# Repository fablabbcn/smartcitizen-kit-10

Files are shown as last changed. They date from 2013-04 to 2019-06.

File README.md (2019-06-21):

Smart Citizen Kit
=================

**NOTE:** [Click here](https://github.com/fablabbcn/smartcitizen-kit-20) for the newer version of SCK 2.0+

**Smart Citizen Kit BETA version for the Ambient Sensor Board.**

SCK

### Download

* Download the latest firmware release [here](https://github.com/fablabbcn/Smart-Citizen-Kit/releases/latest).

### Hardware

* Firmware for the [SmartCitizen Ambient Kit](http://smartcitizen.me/pages/sck) 1.0 and 1.1.

* More hardware info [here](https://github.com/fablabbcn/Smart-Citizen-Kit/tree/master/hardware).

### Quick start

* Visit the project main documentation [docs.smartcitizen.me](http://docs.smartcitizen.me)

### Loading Firmware

**The firmware is totally compatible with Arduino. You can upload the firmware using the [Arduino IDE](http://arduino.cc/en/main/software).**

* For SmartCitizen Kit version 1.0 select `Tools/Boards/Arduino Leonardo` on the Arduino IDE (ATmega 32U4 at 16Mhz) 

* For SmartCitizen Kit version 1.1 select `Tools/Boards/Lylipad Arduino USB` on the Arduino IDE (ATmega 32U4 at 8Mhz) 

### Versions

The current firmware version in use is `0.9.4`.

We currently support the SD card version on as a diferent firmware `SDCARD`, currently `0.8.7 SDCARD`.

You can see the release history [here](https://github.com/fablabbcn/Smart-Citizen-Kit/releases)

You can see the hardware versions [here](https://github.com/fablabbcn/Smart-Citizen-Kit/blob/master/hardware/README.md)

### Advance References

* Setup commands reference in [sck-commands.md](https://github.com/fablabbcn/Smart-Citizen-Kit/blob/master/sck-commands.md)

* Basic documentation for creating your own Sensor Boards [here](https://github.com/fablabbcn/Smart-Citizen-Kit/wiki/Making-a-Shield)

* [Slideshow](https://speakerdeck.com/pral2a/smart-citizen-hardware-and-software) with project technical details

### Support and issues

* Forum [forum.smartcitizen.me](http://forum.smartcitizen.me)

### Contributions

* We are working on improving the firmware documentation for developers but still we encourage you to Fork the project and do a Pull request with your contributions.

## License

All the software unless stated is released under [GNU GPL v3.0](https://github.com/fablabbcn/smartcitizen-kit/blob/master/LICENSE) and the hardware design files under [CERN OHL v1.2](https://github.com/fablabbcn/smartcitizen-kit/blob/master/hardware/LICENSE)

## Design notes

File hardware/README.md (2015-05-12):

Smart Citizen Kit
=================

###Smart Citizen Kit Ambient Sensor Board versions

| Smart Citizen Kit | | SCK 1.0 (Goteo Board) | SCK 1.1 (Kickstarter Board) |
|:---|:---:|:---:|:---:|
| **Data Board** | | | |
| **MCU** | | ATMEGA32U4 | ATMEGA32U4 |
| **Clock** | | 16Mhz | 8Mhz |
| **WiFi** | | Microchip RN-131 802.11 b/g | Microchip RN-131 802.11 b/g |
| **Firmware** | | https://github.com/fablabbcn/Smart-Citizen-Kit | https://github.com/fablabbcn/Smart-Citizen-Kit |
| **Design files** | | https://github.com/fablabbcn/Smart-Citizen-Kit/tree/master/hardware/Goteo/v1.01  | https://github.com/fablabbcn/Smart-Citizen-Kit/tree/master/hardware/Kickstarter |
| **Ambient Board** | | | |
| **Light** | *Part* | PVD-P8001 | BH1730FVC |
| | *Type* | LDR Analog Light Sensor | Digital Ambient Light Sensor |
| | *Units* | % | Lux |
| | *Datasheet* | https://github.com/fablabbcn/Smart-Citizen-Kit/wiki/Datasheets/PDV-P8001.pdf | https://github.com/fablabbcn/Smart-Citizen-Kit/wiki/Datasheets/BH-1730FCV.pdf |
| | Firmware  | `SCKAmbient::getLight();` | `SCKAmbient::getLight():` |
| **Temp** | *Part* | DHT22 | HPP828E031 (SHT21) |
| | *Type* | Digital Temperature and Relative Humidity Sensor | Digital Temperature and Relative Humidity Sensor |
| | *Units* | ºC | ºC |
| | *Datasheet* | https://github.com/fablabbcn/Smart-Citizen-Kit/wiki/Datasheets/DHT22.pdf | https://github.com/fablabbcn/Smart-Citizen-Kit/wiki/Datasheets/HTU-21D.pdf |
| | Firmware  | `SCKAmbient::getDHT22();` `SCKAmbient::getHumidity();` | `SCKAmbient::getSHT21();` `SCKAmbient::getTemperature();` |
| **Humidity** | *Part* | DHT22 | HPP828E031 (SHT21) |
| | *Type* | Digital Temperature and Relative Humidity Sensor | Digital Temperature and Relative Humidity Sensor |
| | *Units* | % Rel | % Rel |
| | *Datasheet* | https://github.com/fablabbcn/Smart-Citizen-Kit/wiki/Datasheets/DHT22.pdf | https://github.com/fablabbcn/Smart-Citizen-Kit/wiki/Datasheets/HTU-21D.pdf |
| | Firmware  | `SCKAmbient::getDHT22();` `SCKAmbient::getHumidity();` | `SCKAmbient::getSHT21();` `SCKAmbient::getHumidity();` |
| **Noise** | *Part* | POM-3044P-R | POM-3044P-R |
| | *Type* | Electret microphone with envelop follower sound pressure sensor | Electret microphone with envelop follower sound pressure sensor |
| | *Units* | dB | dB |
| | *Datasheet* | https://github.com/fablabbcn/Smart-Citizen-Kit/wiki/Datasheets/POM-3044P-R.pdf | https://github.com/fablabbcn/Smart-Citizen-Kit/wiki/Datasheets/POM-3044P-R.pdf |
| | *Firmware*  | `SCKAmbient::getNoise();` | `SCKAmbient::getNoise();` |
| **CO** | *Part* | MICS-5525 | MiCS-4514 |
| | *Type* | MOS CO gas sensor | MOS CO and NO2 gas sensor |
| | *Units* | kOhm (ppm) | kOhm (ppm) |
| | *Datasheet* | https://github.com/fablabbcn/Smart-Citizen-Kit/wiki/Datasheets/MICS-5525_CO.pdf  | https://github.com/fablabbcn/Smart-Citizen-Kit/wiki/Datasheets/MiCS-4514_CO_NO2.pdf |
| | *Firmware*  | `SCKAmbient::getMICS();` | `SCKAmbient::getMICS();` |
| **NO2** | *Part* | MICS-2710 | MiCS-4514 |
| | *Type* | MOS NO2 gas sensor | MOS CO and NO2 gas sensor |
| | *Units* | kOhm (ppm) | kOhm (ppm) |
| | *Datasheet* | https://github.com/fablabbcn/Smart-Citizen-Kit/wiki/Datasheets/MICS-2710_NO2.pdf | https://github.com/fablabbcn/Smart-Citizen-Kit/wiki/Datasheets/MiCS-4514_CO_NO2.pdf |
| | *Firmware*  | `SCKAmbient::getMICS();` | `SCKAmbient::getMICS();` |

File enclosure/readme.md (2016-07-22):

Smartcitizen Kit Enclosure
====

## Enclosure (info [video](https://vimeo.com/145620646))
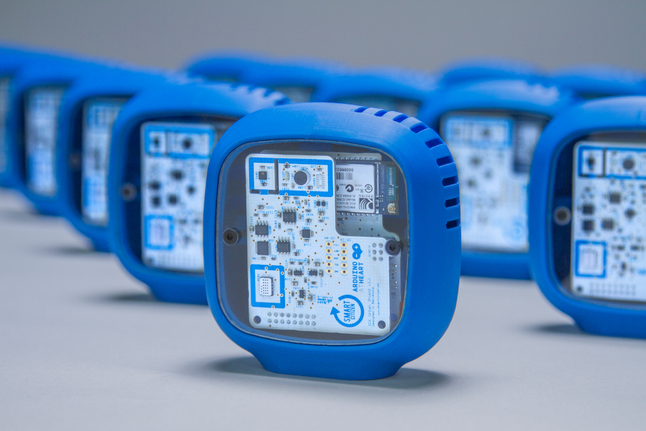
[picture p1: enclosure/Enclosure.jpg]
Enclosure


## Simple base
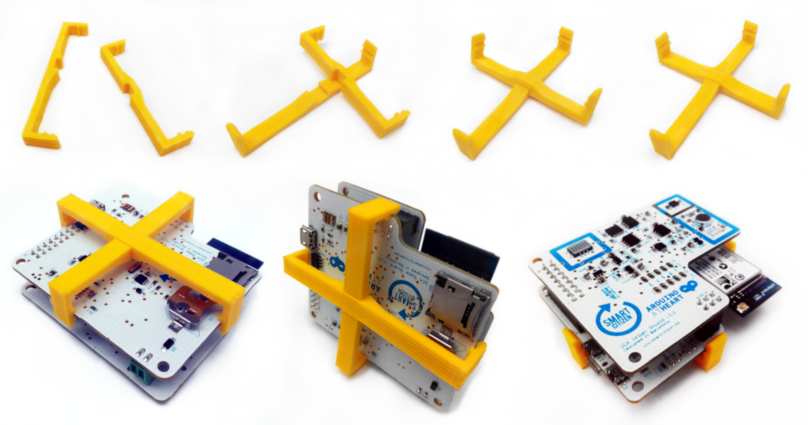
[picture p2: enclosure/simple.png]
Simple base


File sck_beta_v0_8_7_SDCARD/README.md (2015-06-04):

Smart Citizen Kit firmware for SD
=================================

**Smart Citizen Kit SD firmware version for the Ambient Sensor Board.**

This firmware is aimed to people wanting to log data in off-line mode, without internet connectivity, storing data on the built-in micro SD.

##Steps

1. **microSD**: We recomend formating **micro SD** cards using the official SD tool you can download [here](https://www.sdcard.org/downloads/formatter_4/).

2. **RTC**: Place a **CR1220** cell battery on your kit. Before uploading the SD firmware use the on-line configuration tool at [smartcitizen.me](https://smartcitizen.me) to set your Wi-Fi credentials. Your kit will connect to the internet and sync its the internal clock with our remote servers.

3. You can now install the **SD firmware** using the Arduino IDE. Ready!

##Installation

**The firmware is totally compatible with Arduino. You can upload the firmware using the [Arduino IDE](http://arduino.cc/en/main/software).**

####Dependencies: 

In order to compile and upload the firmware you will need to install the **SdFat** library for Arduino.

Download the library [here](https://github.com/greiman/SdFat) and install the library following the [instructions](http://arduino.cc/en/Guide/Libraries).

####Boards:

* For SmartCitizen Kit version 1.0 select `Tools/Boards/Arduino Leonardo` on the Arduino IDE (ATmega 32U4 at 16Mhz) 

* For SmartCitizen Kit version 1.1 select `Tools/Boards/Lylipad Arduino USB` on the Arduino IDE (ATmega 32U4 at 8Mhz) 

##SD data format

When using the **SD firmware** on the SCK, data is stored as **CSV** (comma separated) file on the SD card.

This is an example of the output file once opened on a spreadsheet application:

| Temperature | Humidity| Light | Battery | Solar Panel | CO | NO2  | Noise| UTC			  	 | 
|---|---|---|---|---|---|---|---|---|
| 2821.20 | 4072.00 | 4413.10 | 96.40 | 0.00 | 94.67  | 0.65 | 5.23 | 2000-01-01  00:00:02 |
| 2784.40 | 4236.80 | 5936.70 | 96.10 | 0.00 | 278.27 | 1.05 | 2.39 | 2000-01-01  00:00:02 |

###Data Import

You can import the recorded data in to [smartcitizen.me](http://smartcitizen.me).

In your device page you will find the **Import SD** along with the Edit and Configure options.



Using a microSD card reader get the **post.csv** file from your card, select it and click import. Data will be imported in to your device, data existing on the file already imported will be skipped. Your kit should be running the latest SD firmware  and the SCK time (RTC) should be set in order data can be imported.

###Data Conversions

The data stored is automatically converted to the proper units in firmware.

If you prefer to do the conversions manually set `DataRaw       false` in the `Constants.h` file and apply the formulas on the following table:

| ID  | Sensor | Units | Conversion Formula 
|-----|---|---|---|
| 0 | Temperature  | ºC |  T = -53 + 175.72 / 65536.0 * ( Traw * 10 ) |
| 1 | Humidity | %Rel  |  H = 7 + 125.0  / 65536.0 * ( Hraw * 10 ) |
| 2 | Light | Lux |  L = Lraw / 10 |
| 3 | Battery | % |  Not required |
| 4 | Panel | mV |  Not required | 
| 5 | CO 	  | kOhm  |  Not required | 
| 6 | NO2 | kOhm  |  Not required | 
| 7 | Noise | dB |  Apply the conversion table from mV to dB: [CSV](https://gist.github.com/pral2a/d767cc45874361fd38bf) 
| 8 | Date | DD:MM:YY |  Not required | 
| 9 | Time | hh:mm:ss |  Not required |

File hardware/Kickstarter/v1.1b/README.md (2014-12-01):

Smart-Citizen-Kit
=================

Eagles files of the Kickstarter campaign

[https://www.kickstarter.com/projects/acrobotic/the-smart-citizen-kit-crowdsourced-environmental-m
](https://www.kickstarter.com/projects/acrobotic/the-smart-citizen-kit-crowdsourced-environmental-m)

Smart Citizen Kit BETA version
- Base Board v1.1b
- Ambient Sensor Board v1.1b

The SCK is a piece of hardware comprised by two printed-circuit boards: an interchangeable daughterboard or shield, and an arduino-compatible data-processing board.

The sensor board carries sensors that measure air composition (CO and NO2), temperature, light intensity, sound levels, and humidity. Once it's set up, the ambient board is able to stream data measured by the sensors over Wi-Fi using the FCC-certified, wireless module on the data-processing board.

LICENSE: GPL v.0.3

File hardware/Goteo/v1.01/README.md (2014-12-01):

Smart-Citizen-Kit
=================

Eagles files of Goteo.org campaign, 2n release

[http://www.goteo.org/project/smart-citizen-sensores-ciudadanos?lang=en
](http://www.goteo.org/project/smart-citizen-sensores-ciudadanos?lang=en)

Smart Citizen Kit BETA version
- Base Board v1.01
- Ambient Sensor Board v1.01

The SCK is a piece of hardware comprised by two printed-circuit boards: an interchangeable daughterboard or shield, and an arduino-compatible data-processing board.

The sensor board carries sensors that measure air composition (CO and NO2), temperature, light intensity, sound levels, and humidity. Once it's set up, the ambient board is able to stream data measured by the sensors over Wi-Fi using the FCC-certified, wireless module on the data-processing board.

LICENSE: GPL v.0.3

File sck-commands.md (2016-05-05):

## SCK Serial Commands

The Smart Citizen Kit can be managed over a basic serial protocol. You just need the **Arduino IDE Serial Monitor** or any other **Serial Utility** like **Screen** in order to use it.

#### How to use it.

* Connect to your kit using any serial utility, any baud-rate should work but `115200` is recommendable.
* Send the starting commands.
* Notice all the commands except the starting commands require a carriage return at the end: `CR` or `\r`  .
* Call any command you want, change `XXX` with the corresponding value.

### Basic SCK setup commands

This commands are commands to talk directly to the Wi-Fi module (RN-XV WiFly) own interface.

* `$$$`							Wake up the module and enter WiFly commands mode
* `set wlan ssid XXX\r`        Add a new SSID to memory
* `set wlan phrase XXX\r`      Add a new phrase to memory
* `set wlan key XXX\r`         Add a new key to memory
* `set wlan auth XXX\r`        Add an authentication method into memory
* `set wlan ext_antenna XXX\r` Add an antenna type into memory
* `set sys iofunc 0x7`         Disable the Wi-Fi module blue LED's 
* `exit\r`                     Go back to normal operational mode

### Special SCK commands

This commands are commands to talk talk to the SCK configuration interface.

* `###`							Wake up the module and enter SCK commands mode
* `get mac\r`                  Get the MAC address of the kit
* `get time update\r`          Retrieve the sensor update interval
* `set time update XXX\r`    	Update the sensor update interval
* `get number updates\r`    	Retrieve the max number of bulk updates allowed
* `set number updates XXX\r`   Update the max number of bulk updates allowed
* `get apikey\r`               Retrieve the kit APIKEY
* `set apikey XXX\r`           Update the kit APIKEY
* `get wlan ssid\r`            Retrieve the SSID saved on the kit
* `get wlan phrase\r`          Retrieve the phrase and KEY saved on the kit
* `get wlan auth\r`            Retrieve the authentication methods saved on the kit
* `get wlan ext_antenna\r`     Retrieve the antenna types saved on the kit
* `get all\r`                  Retrieve all config saved on the kit in a single line (`|version|MAC|ssid1 ssid2,pass1 pass2,auth1 auth2,ant1 ant2|hardcodedNets|timeUpdate|numPosts|`)
* `post data\r`                Retrieve sensor readings and post them to server if network connection is available.
* `clear nets\r`               Remove all saved Wi-Fi configuration information (except hardcoded)
* `clear memory\r`             Remove all configuration information
* `exit\r`                     Goes back to normal operational mode
* `#data\r`  					Retrieves sensor readings stored in memory

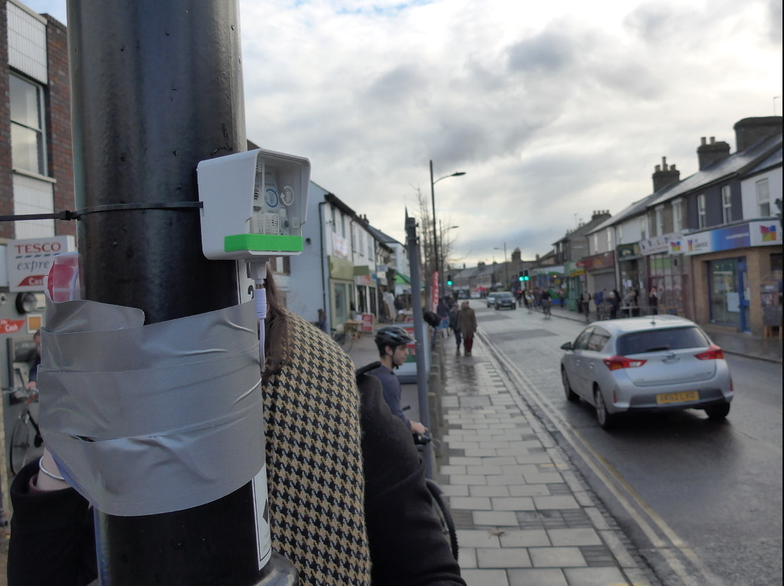
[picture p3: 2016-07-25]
enclosure/Basic_case-2013/SCK_basic-1.jpg

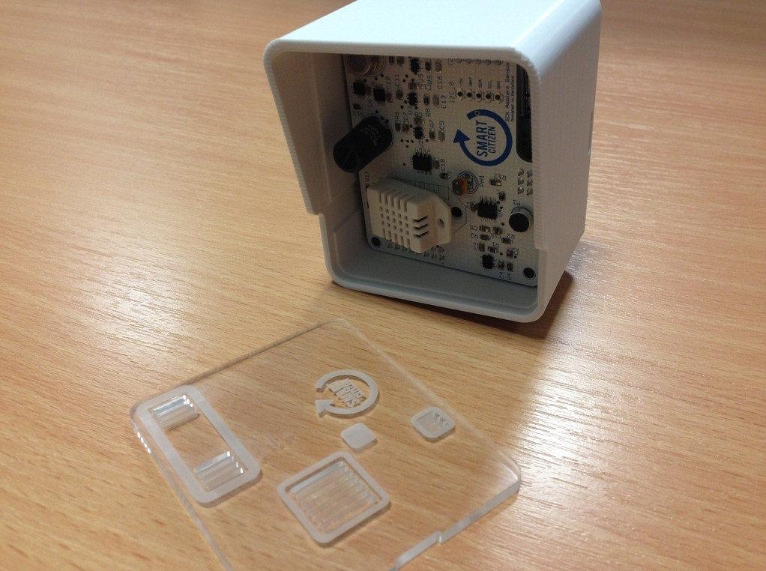
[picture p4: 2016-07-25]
enclosure/Basic_case-2013/SCK_basic-4.jpg

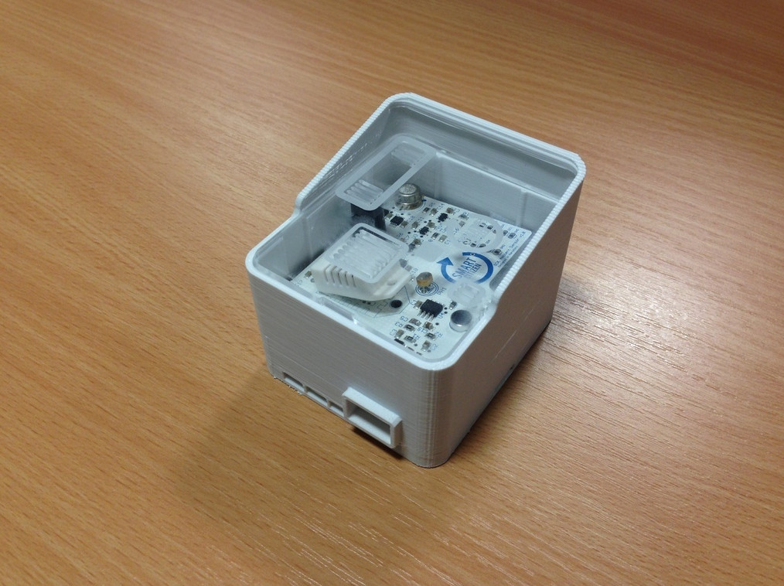
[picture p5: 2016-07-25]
enclosure/Basic_case-2013/SCK_basic-3.jpg

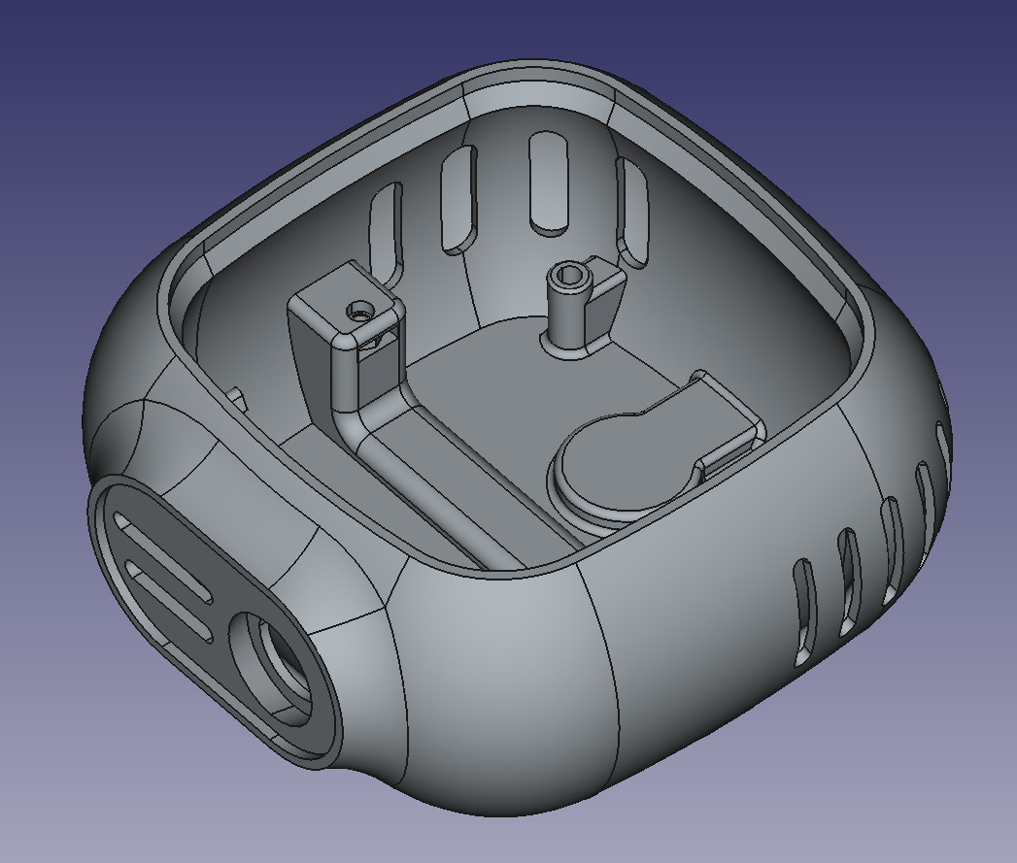
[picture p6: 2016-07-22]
enclosure/case/case.jpg

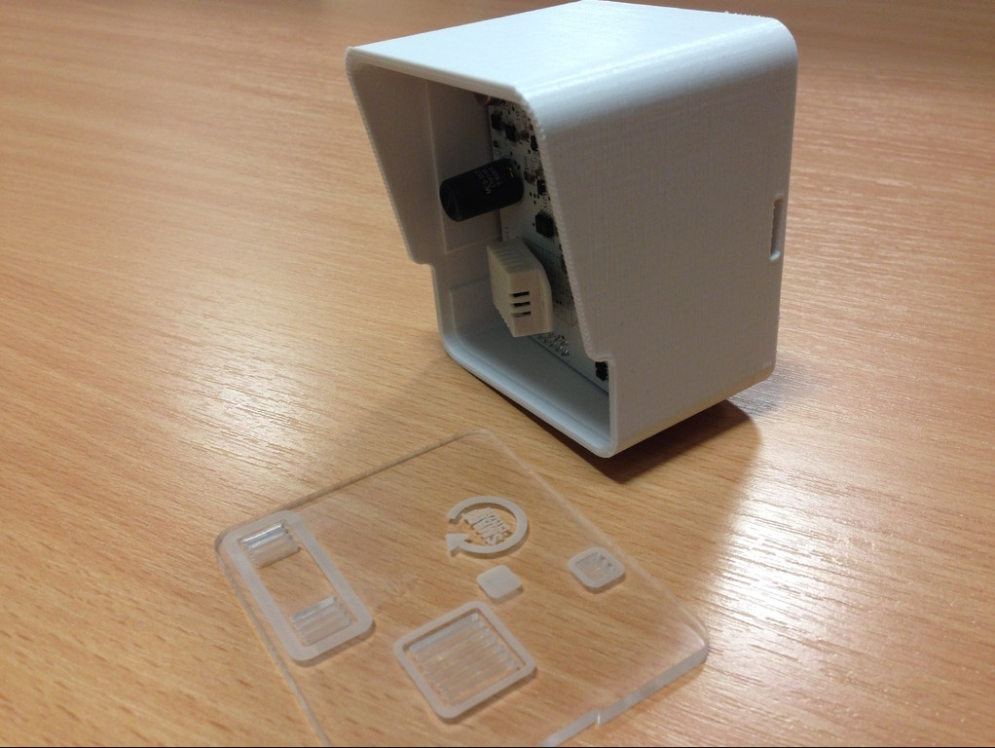
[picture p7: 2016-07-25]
enclosure/Basic_case-2013/SCK_basic-2.jpg

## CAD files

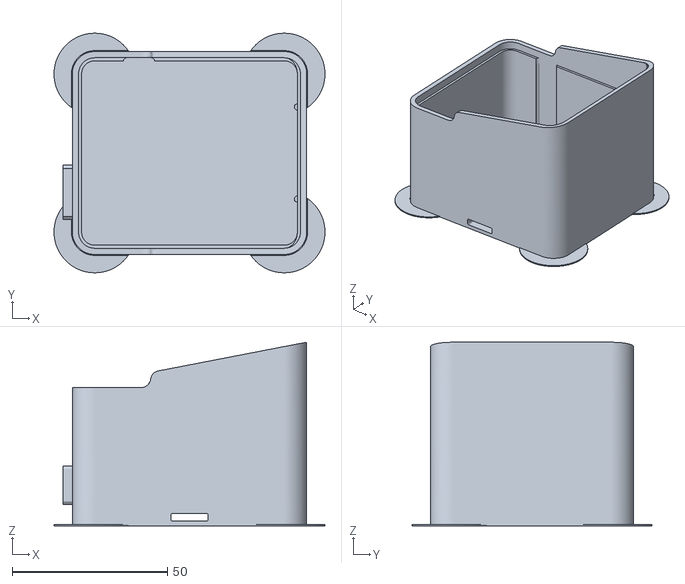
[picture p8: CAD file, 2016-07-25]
enclosure/Basic_case-2013/SCK-1.0/SCK-1.0_case.stl
87.3 x 77.2 x 59.2

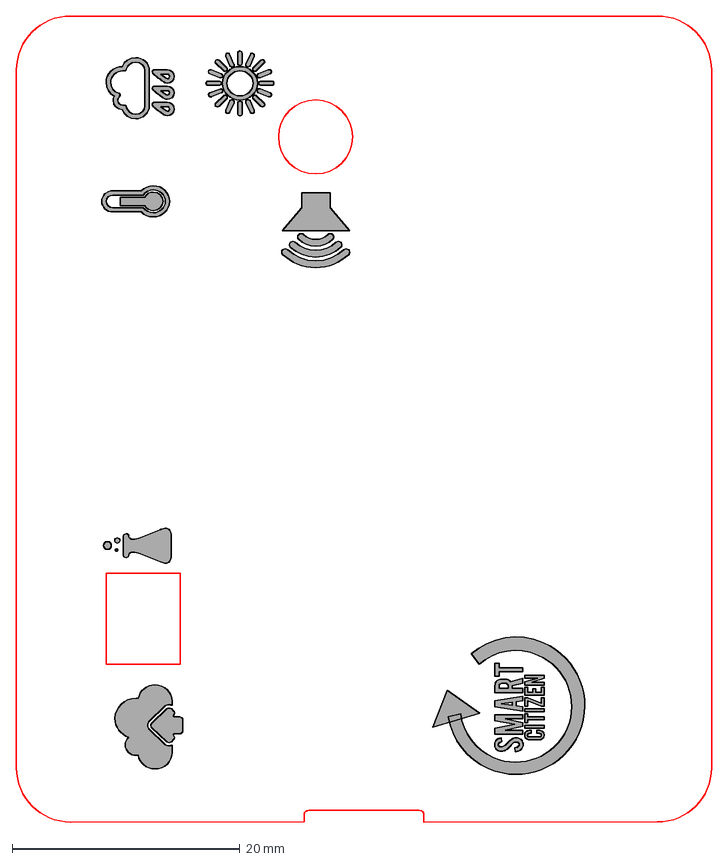
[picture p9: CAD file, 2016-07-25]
enclosure/Basic_case-2013/SCK-1.1/SCK-1.1_acrylic.dxf
61.0 x 70.7 mm

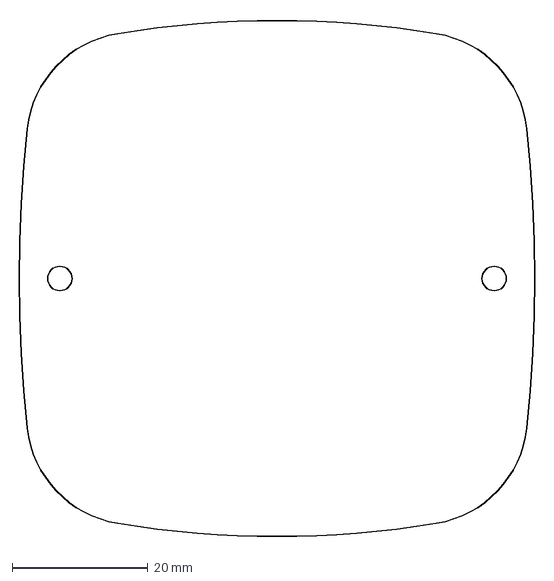
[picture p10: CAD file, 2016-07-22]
enclosure/case/SCK-1.1_case_acrylic.dxf
76.8 x 77.3 mm

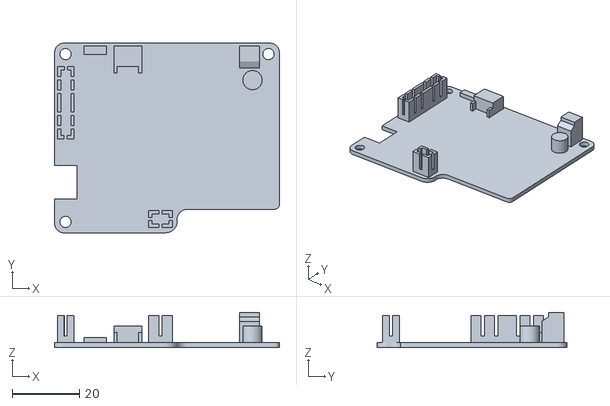
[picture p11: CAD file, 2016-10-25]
enclosure/dummybaseplate2.stl
66.9 x 56.5 x 10.5

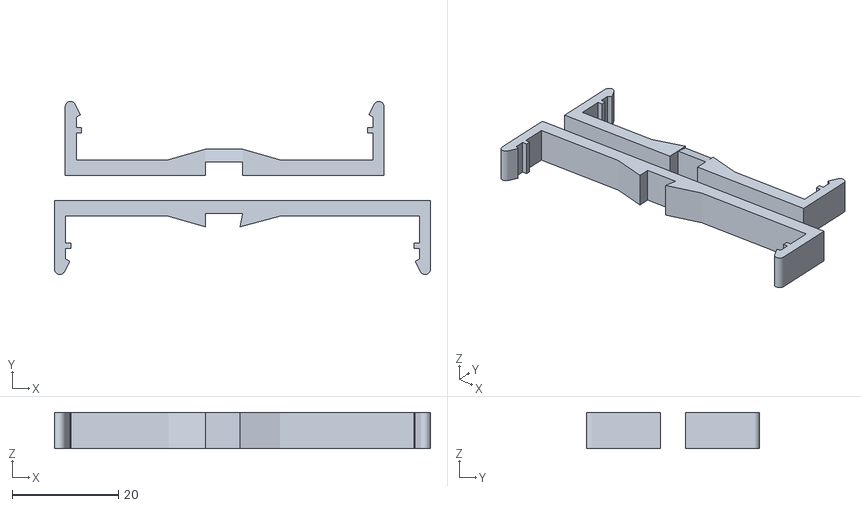
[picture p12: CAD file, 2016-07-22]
enclosure/Simple_base/SCK-1.1_simple_base.stl
70.8 x 32.6 x 6.78

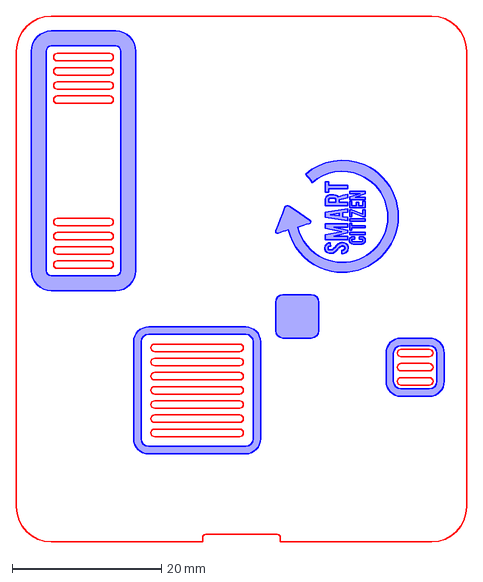
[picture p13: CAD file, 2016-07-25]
enclosure/Basic_case-2013/SCK-1.0/SCK-1.0_acrylic.dxf
60.3 x 70.4 mm

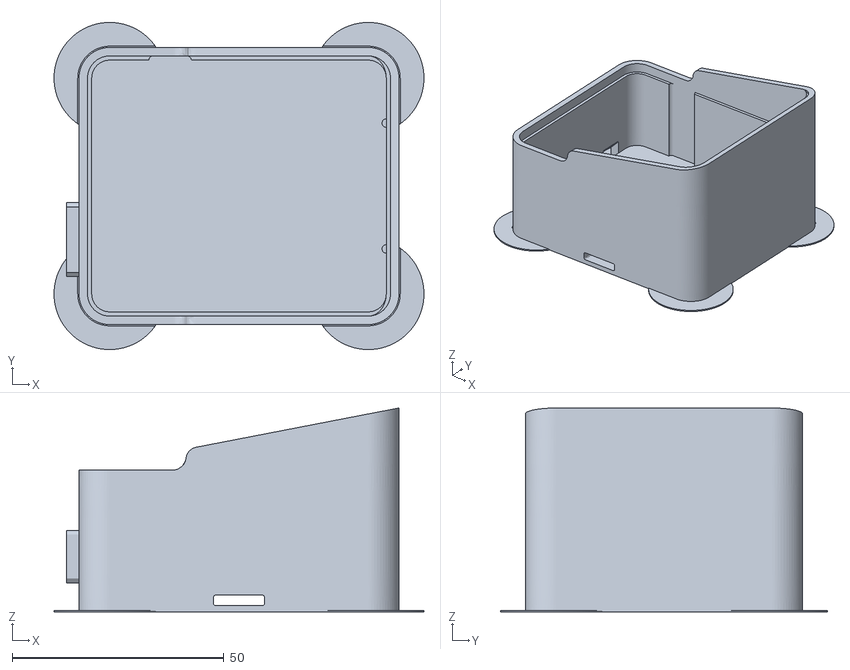
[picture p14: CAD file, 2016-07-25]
enclosure/Basic_case-2013/SCK-1.1/SCK-1.1_case.stl
87.3 x 77.2 x 48.1

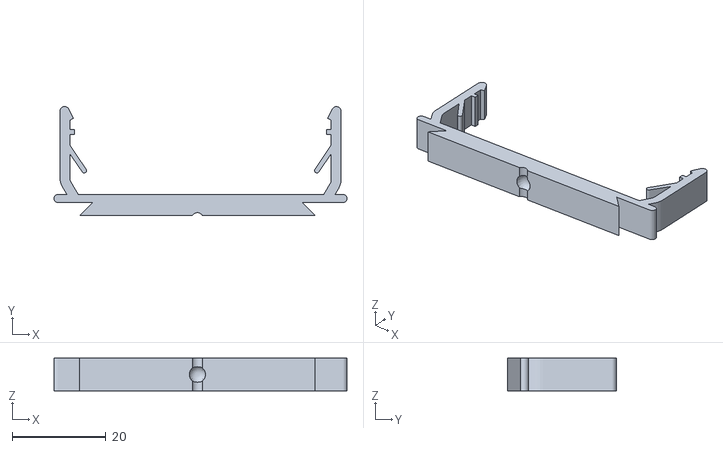
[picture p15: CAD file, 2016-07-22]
enclosure/case/SCK-1.1_case_clip.stl
62.6 x 23.3 x 7.00

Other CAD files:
enclosure/Basic_case-2013/SCK-1.1/SCK-1.1_case.3dm

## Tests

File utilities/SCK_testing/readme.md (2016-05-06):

Smartcitizen Kit testing script
=================

#### A python script to test and update Smartcitizen kits

##### It's a command line utility aimed to check the different parts of a kit and apply available updates in the most possible automated way.

* Checks wifly firmware version and installs available updates.
* Installs the latest available firmware from github (after first installation if you want to refresh the firmware, delete the folder named *"firmware"* before running the script again)
* Takes readings from sensors and checks if values are inside an acceptable range (*work in progress*).
* Creates a csv file with the results of the tests with one entry per tested kit.

------
##### Using the script

* This script requires a working installation of [python](https://www.python.org/) and [Arduino IDE](https://www.arduino.cc/en/Main/Software) and a working Internet connection with wi-fi access.
* Download this folder to your computer, edit your network settings on line 9-10, connect your kit  to the USB port and run the script with `python SCKtester`.
* If you only have the kit connected to your computer and only one serial port is available, you can skip port selection with the *-p* option: `python SCKtester -p`

------
##### Screenshot
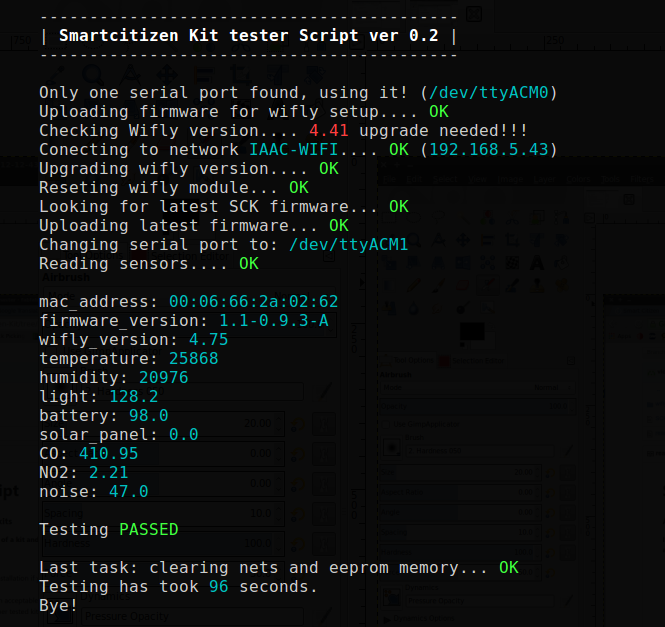
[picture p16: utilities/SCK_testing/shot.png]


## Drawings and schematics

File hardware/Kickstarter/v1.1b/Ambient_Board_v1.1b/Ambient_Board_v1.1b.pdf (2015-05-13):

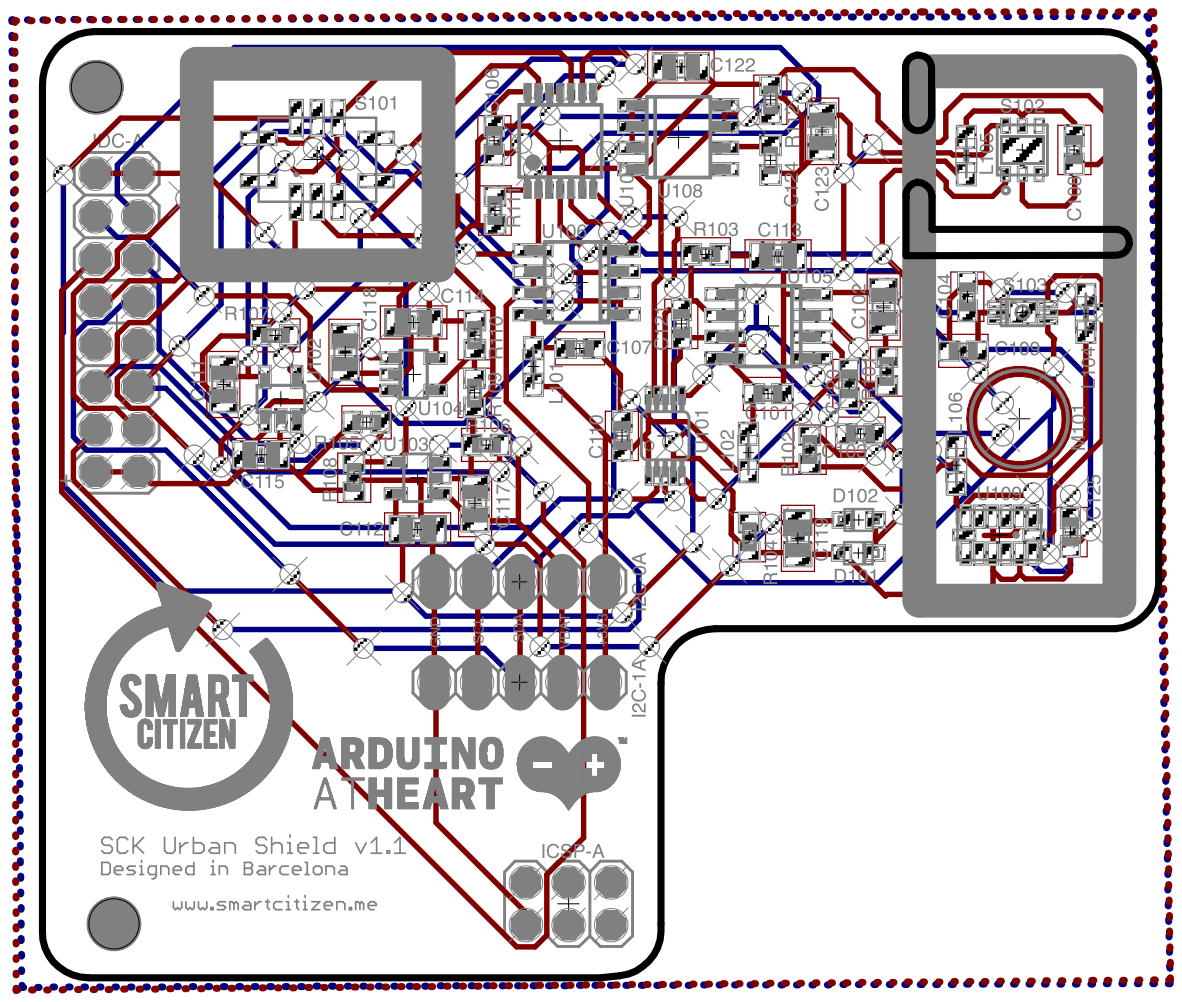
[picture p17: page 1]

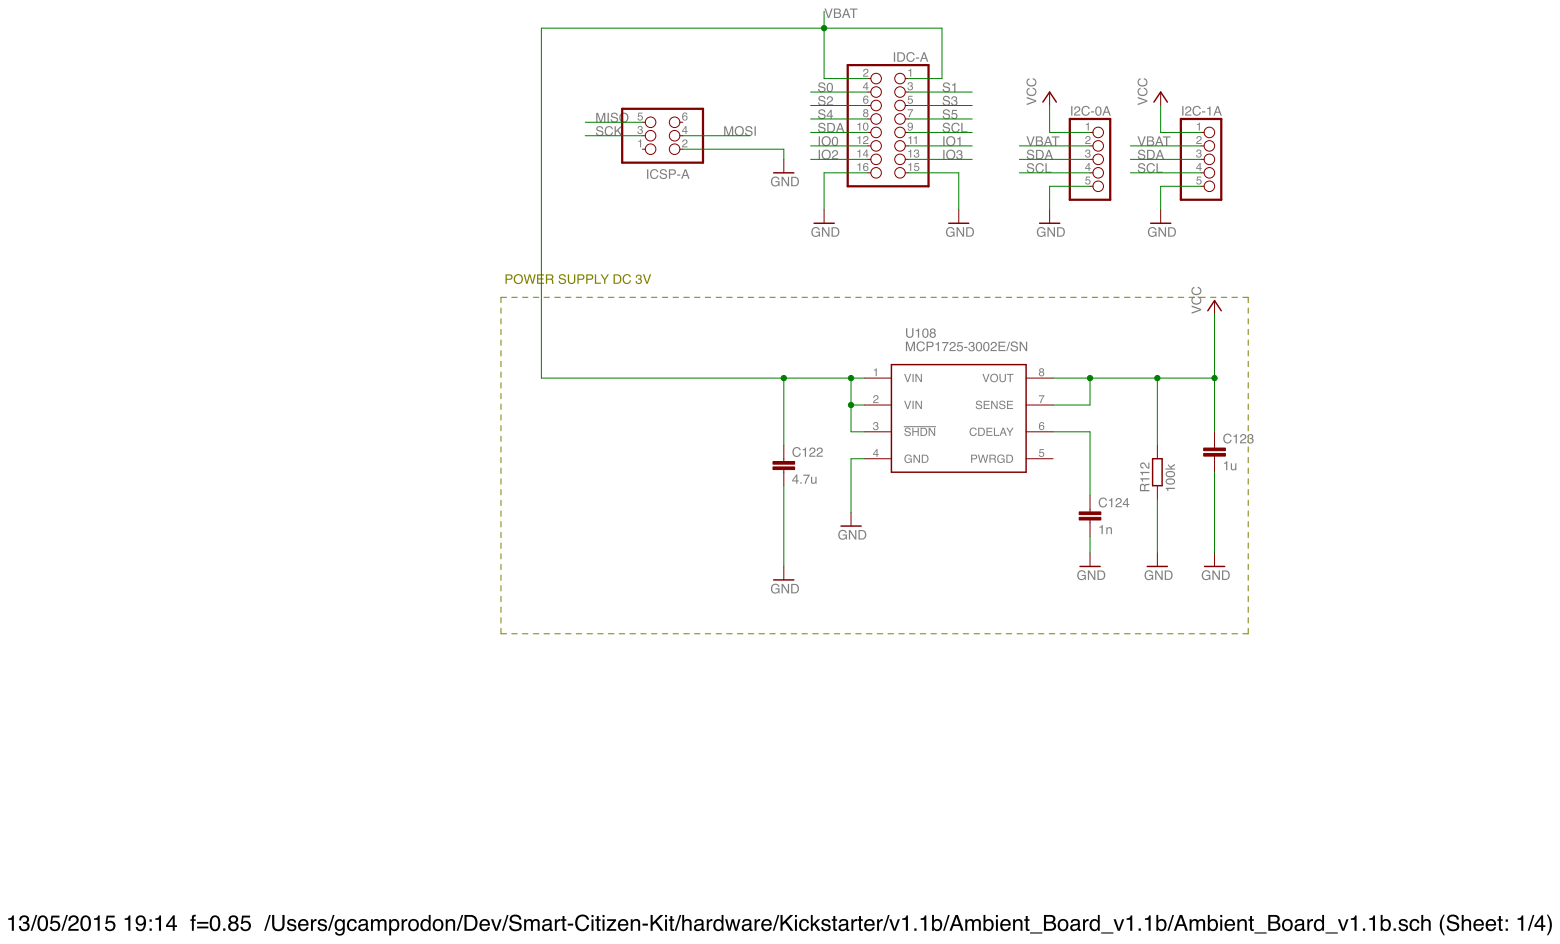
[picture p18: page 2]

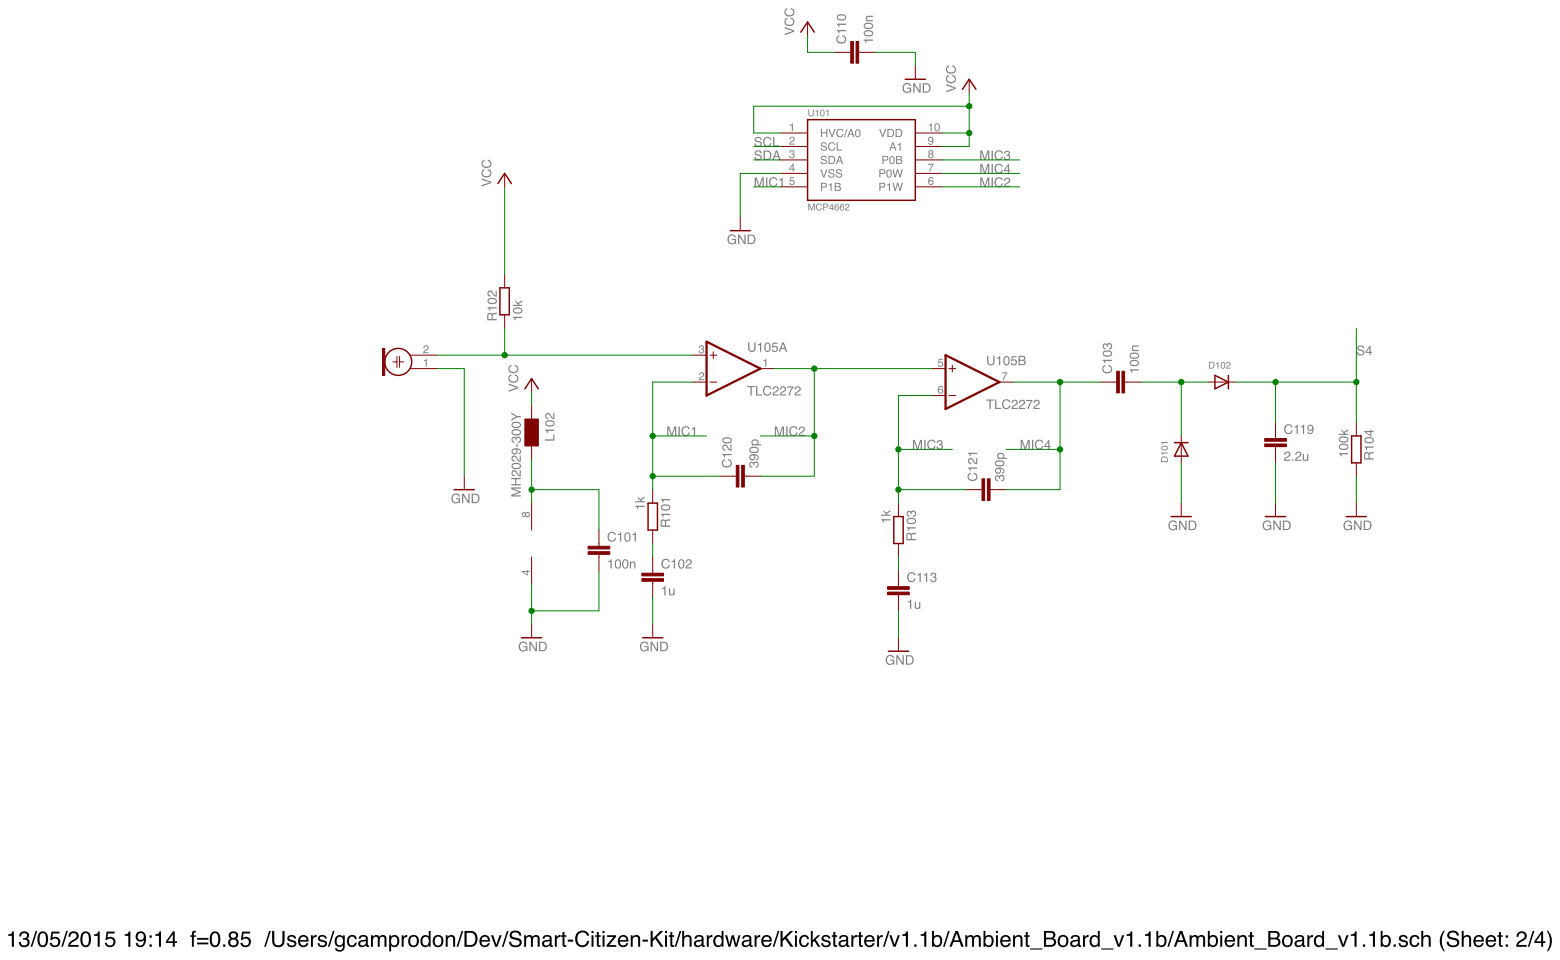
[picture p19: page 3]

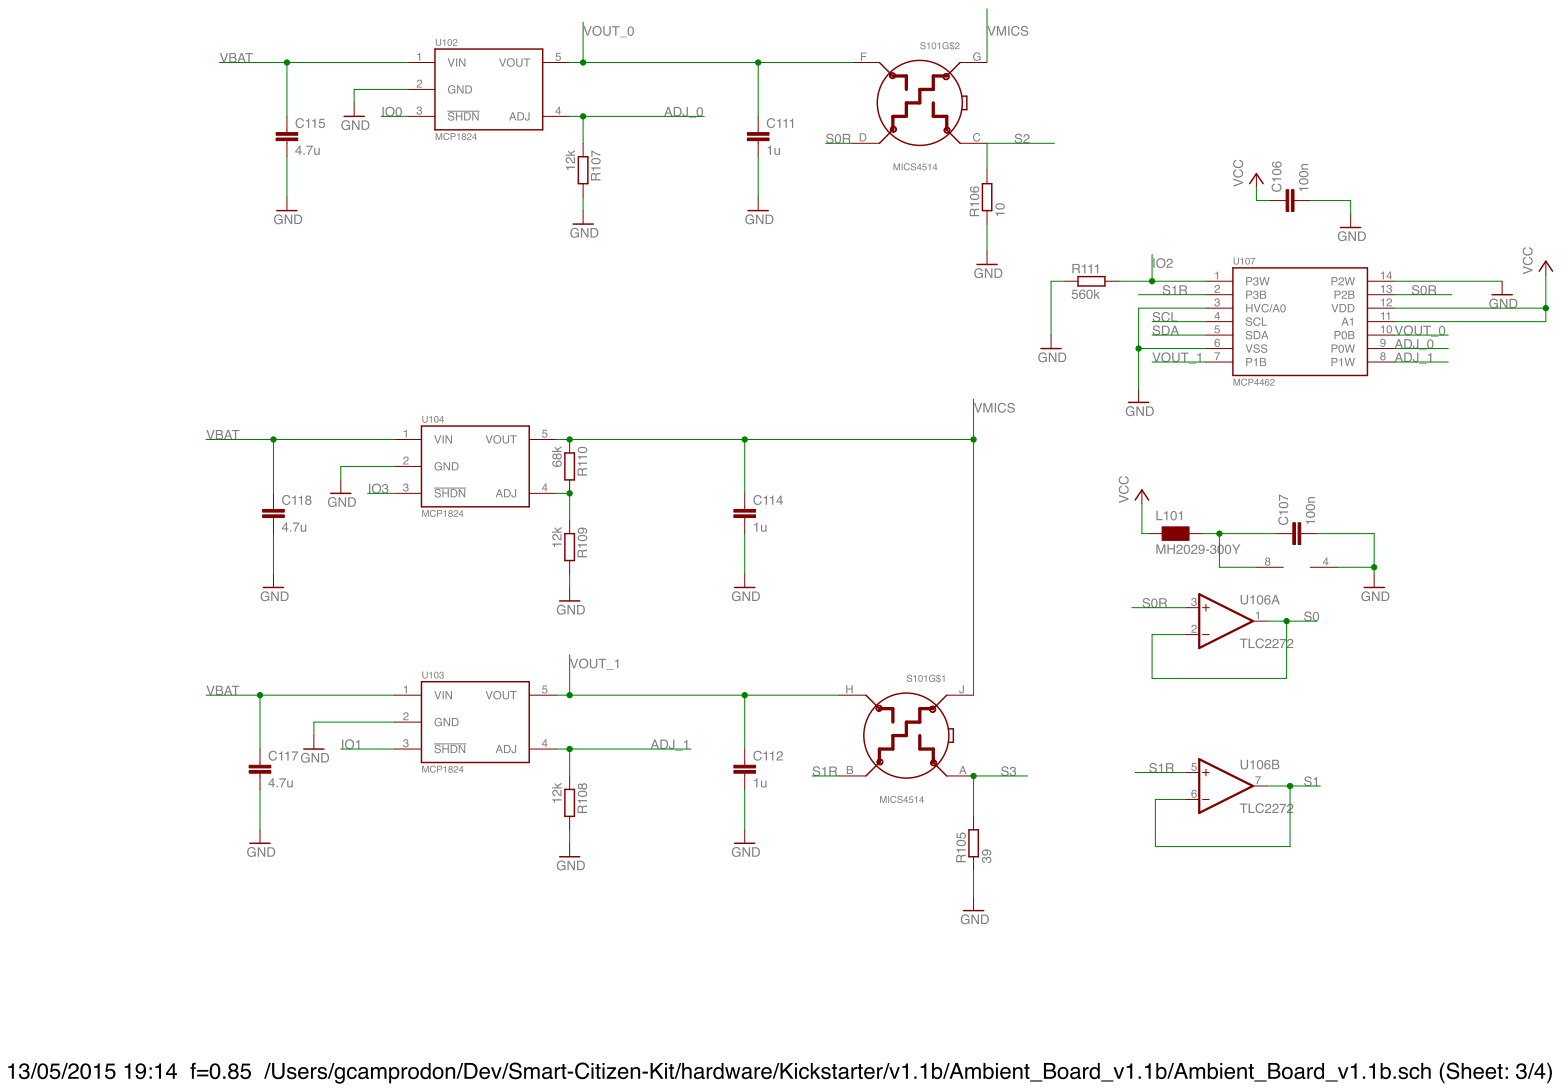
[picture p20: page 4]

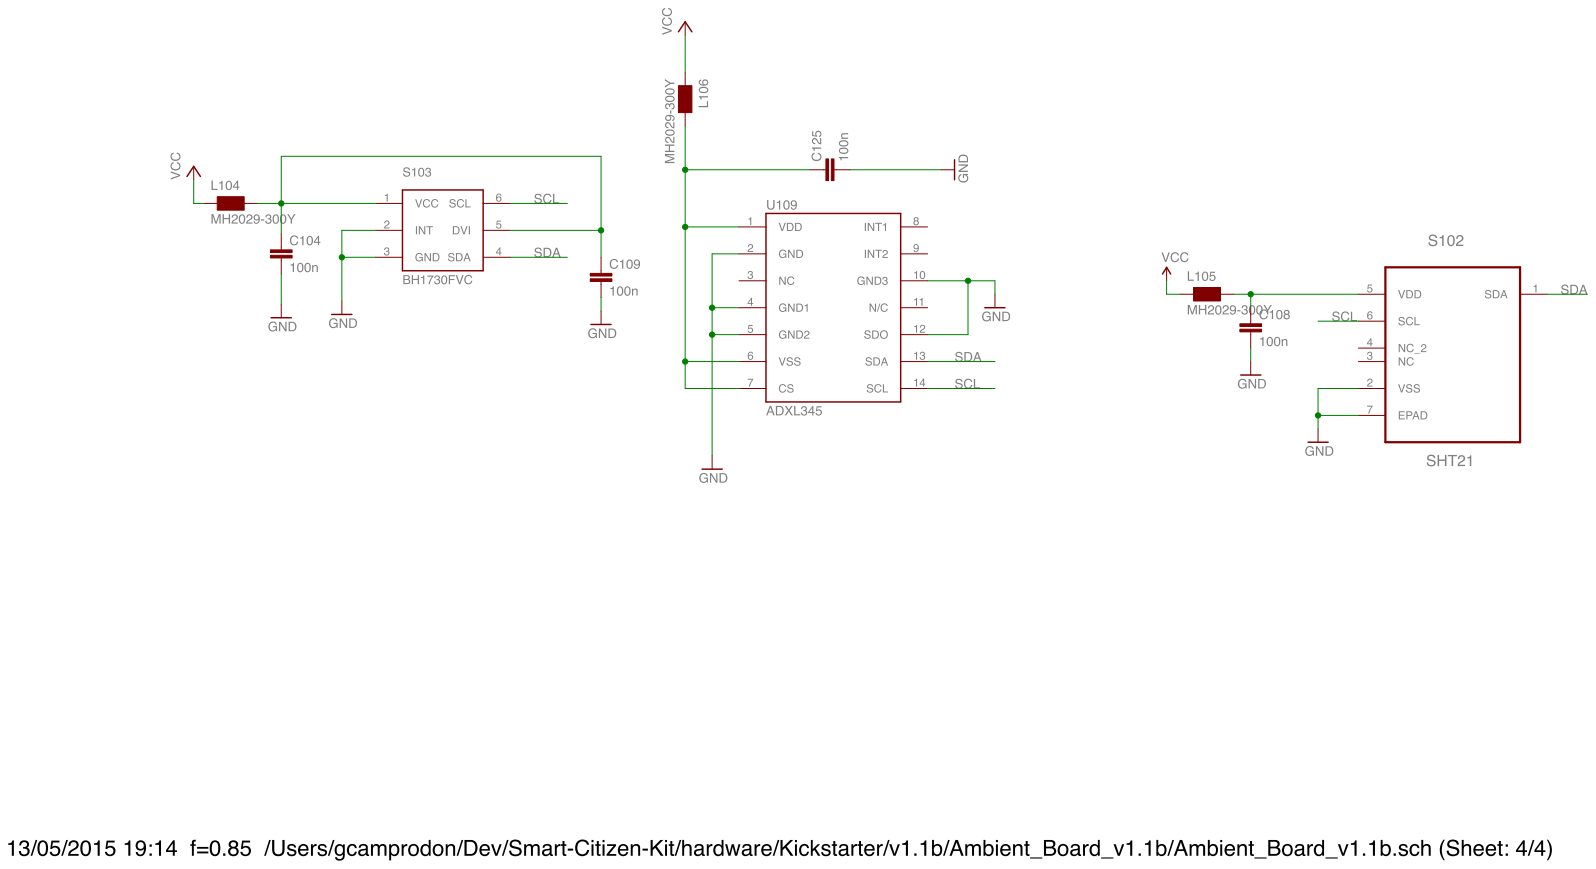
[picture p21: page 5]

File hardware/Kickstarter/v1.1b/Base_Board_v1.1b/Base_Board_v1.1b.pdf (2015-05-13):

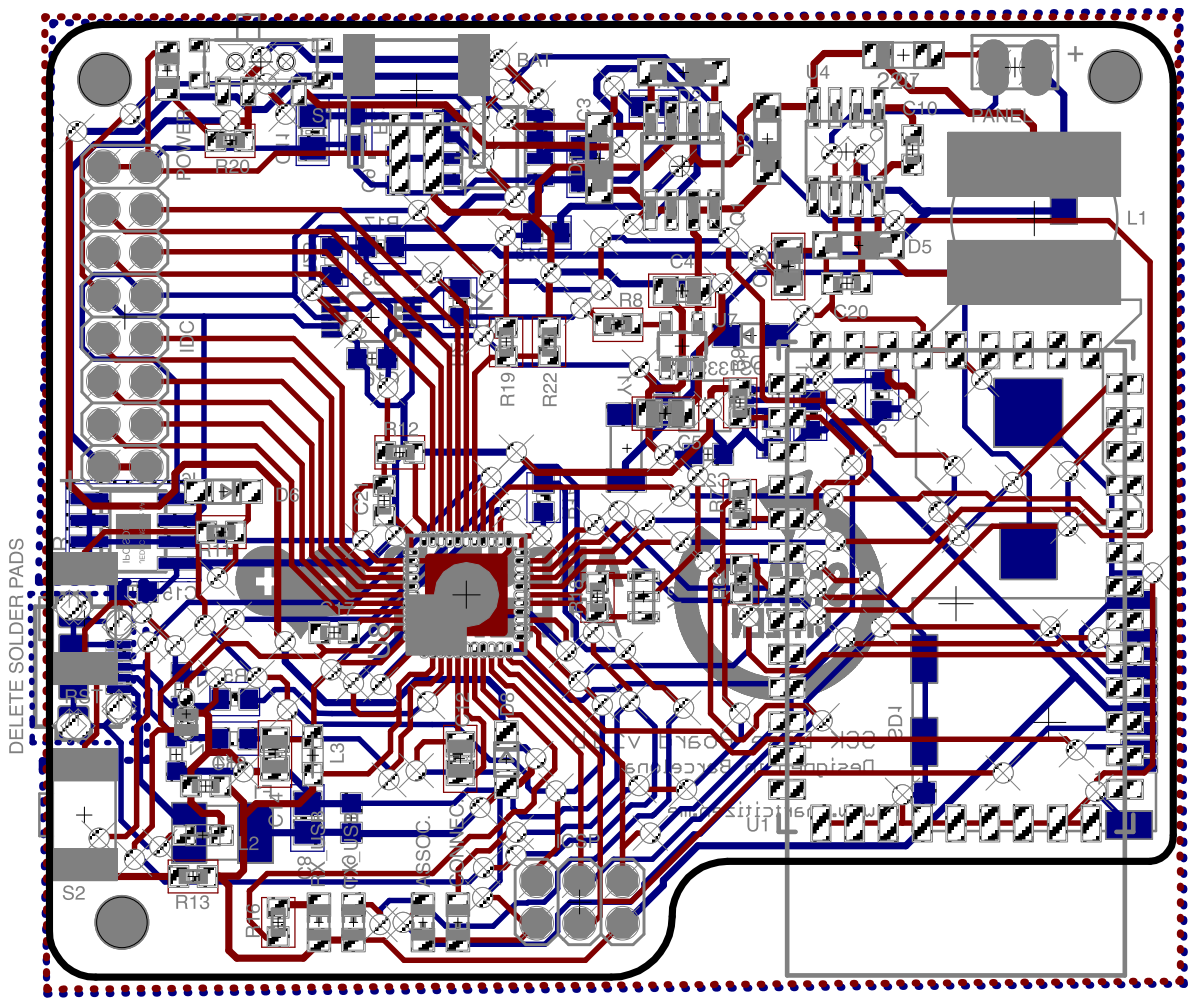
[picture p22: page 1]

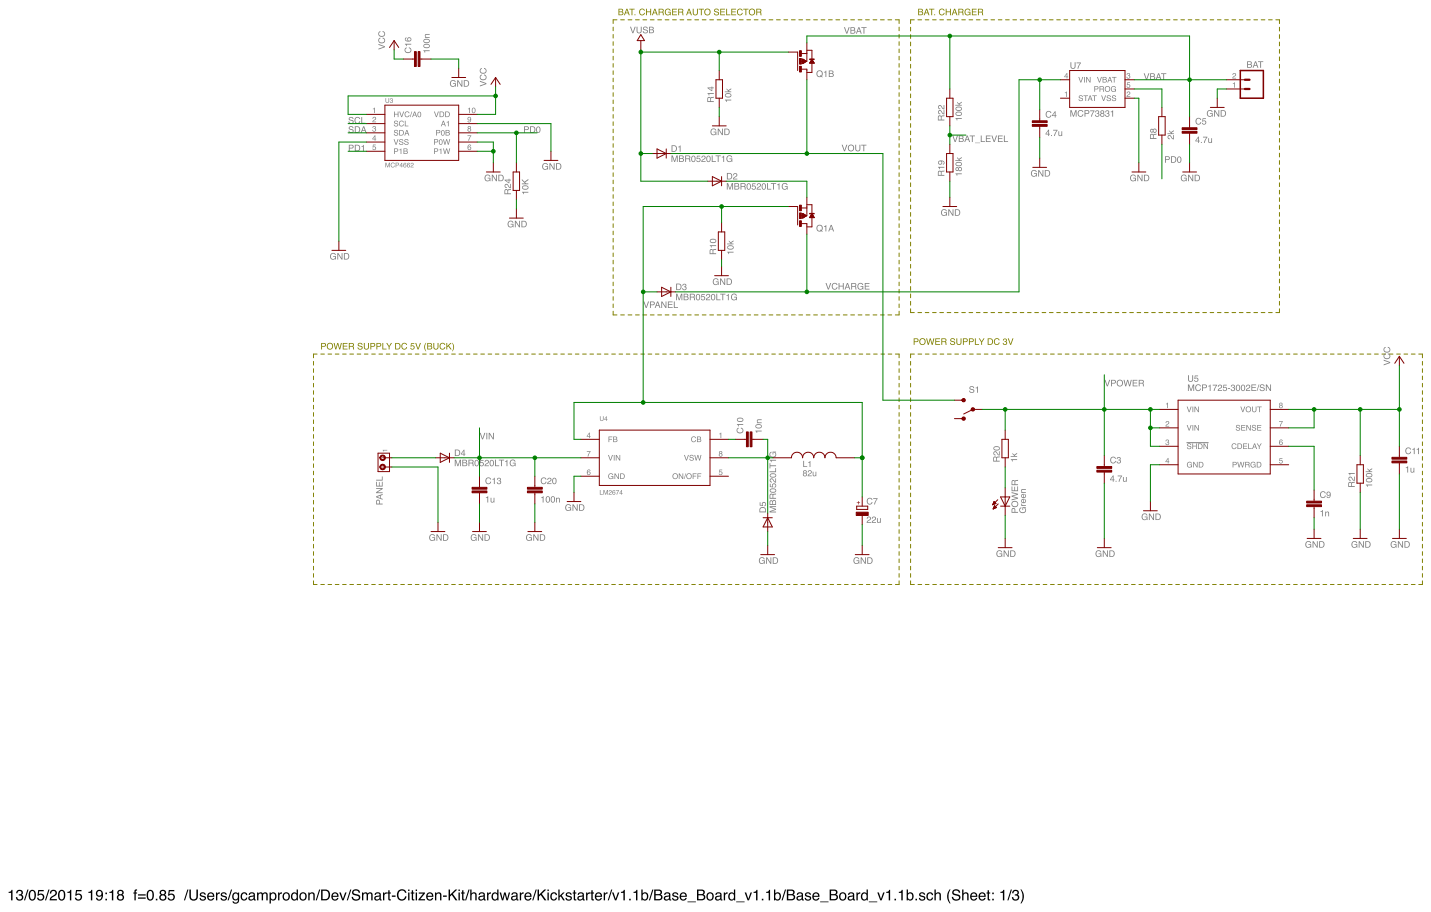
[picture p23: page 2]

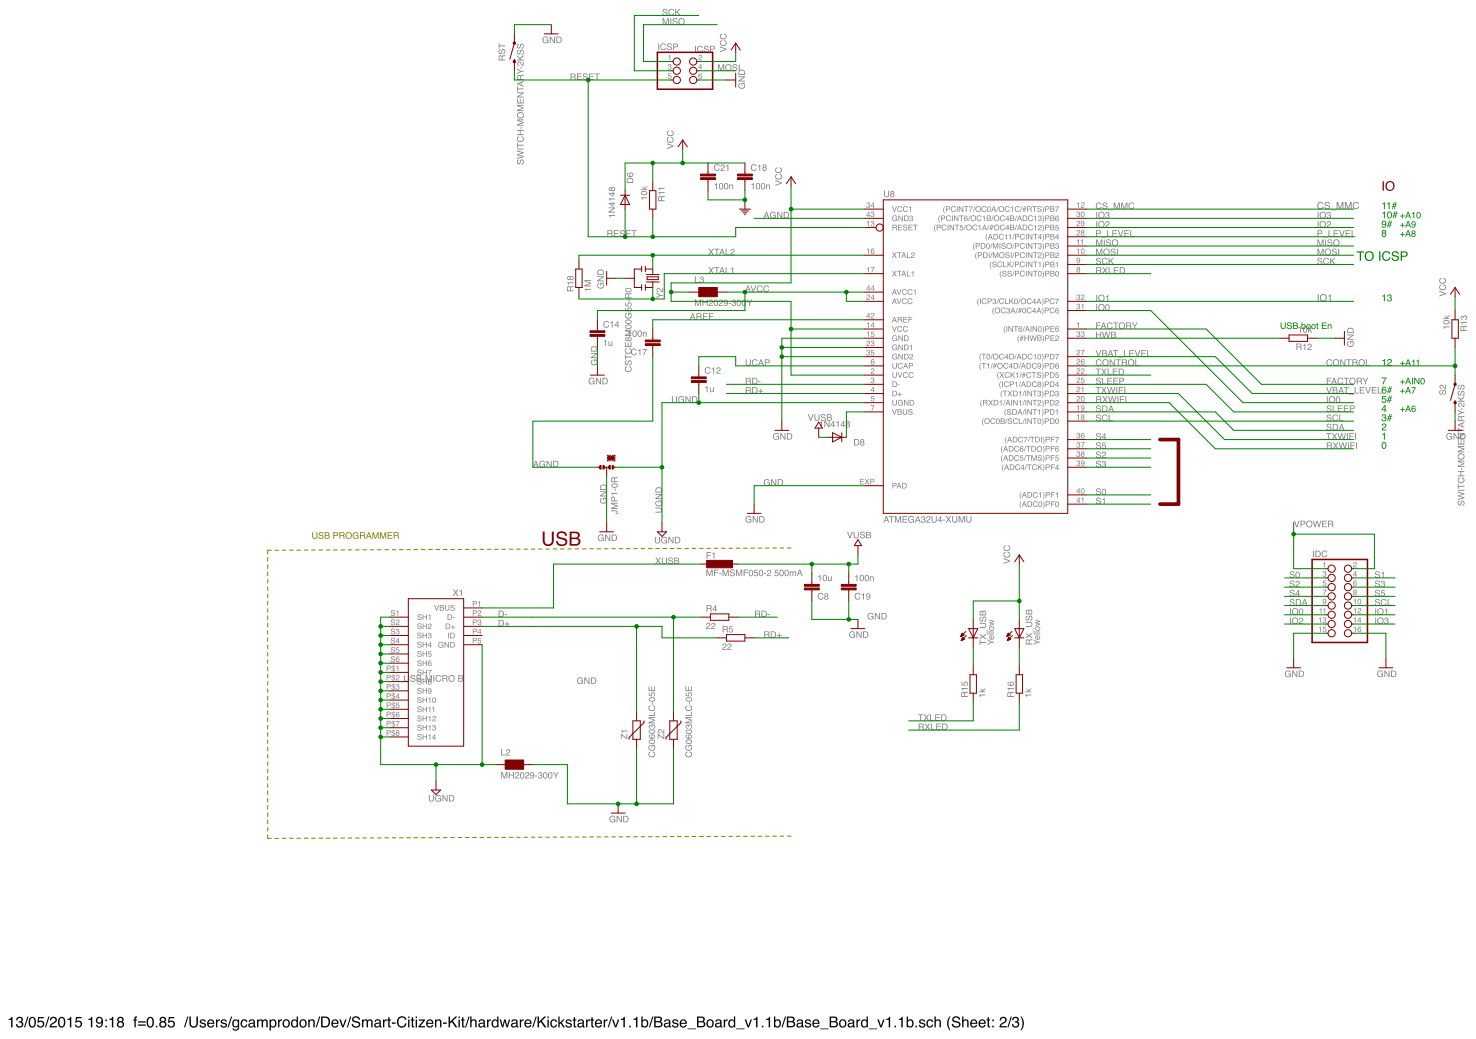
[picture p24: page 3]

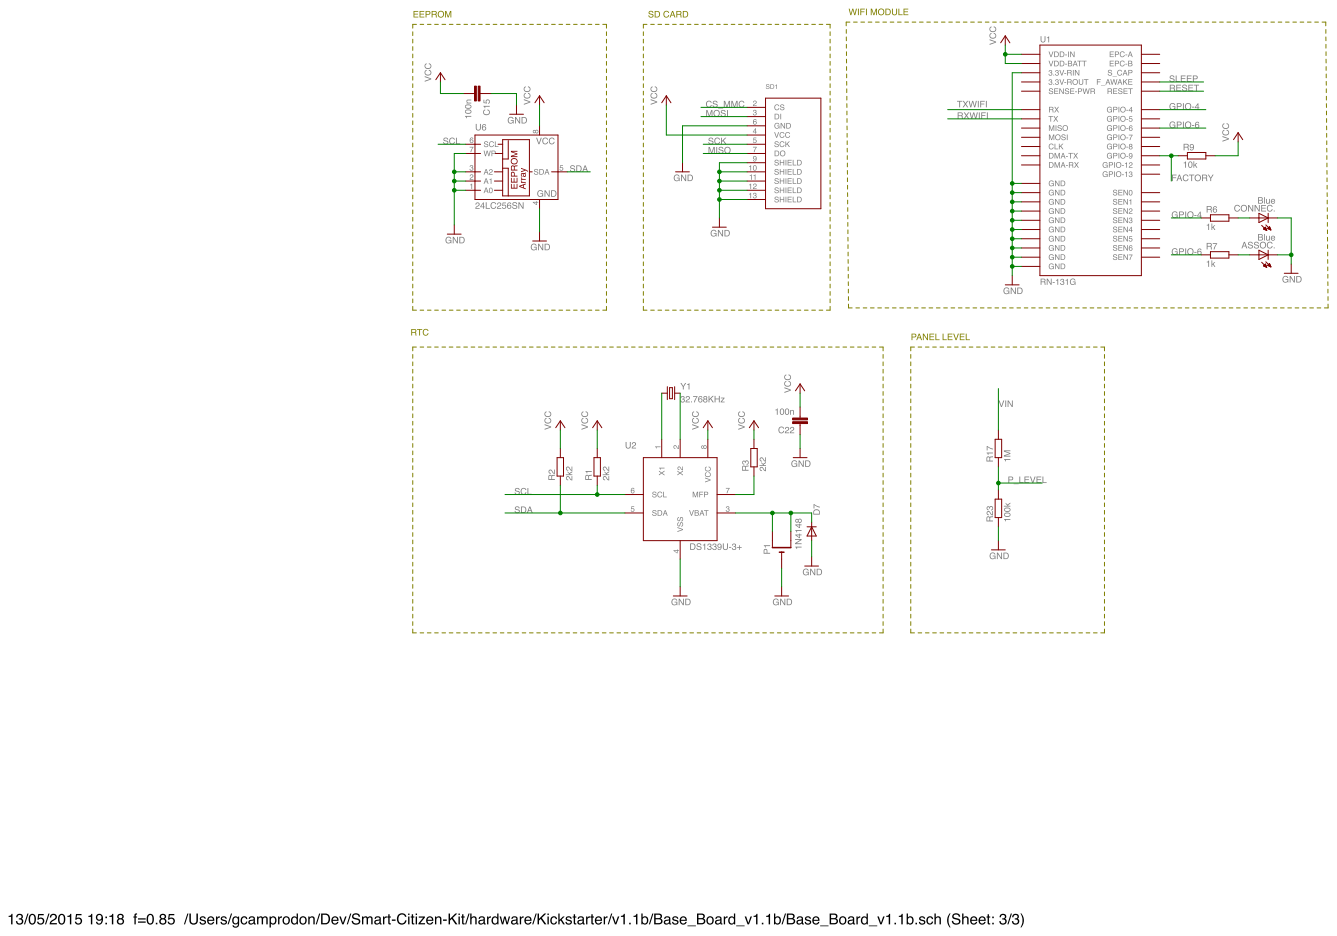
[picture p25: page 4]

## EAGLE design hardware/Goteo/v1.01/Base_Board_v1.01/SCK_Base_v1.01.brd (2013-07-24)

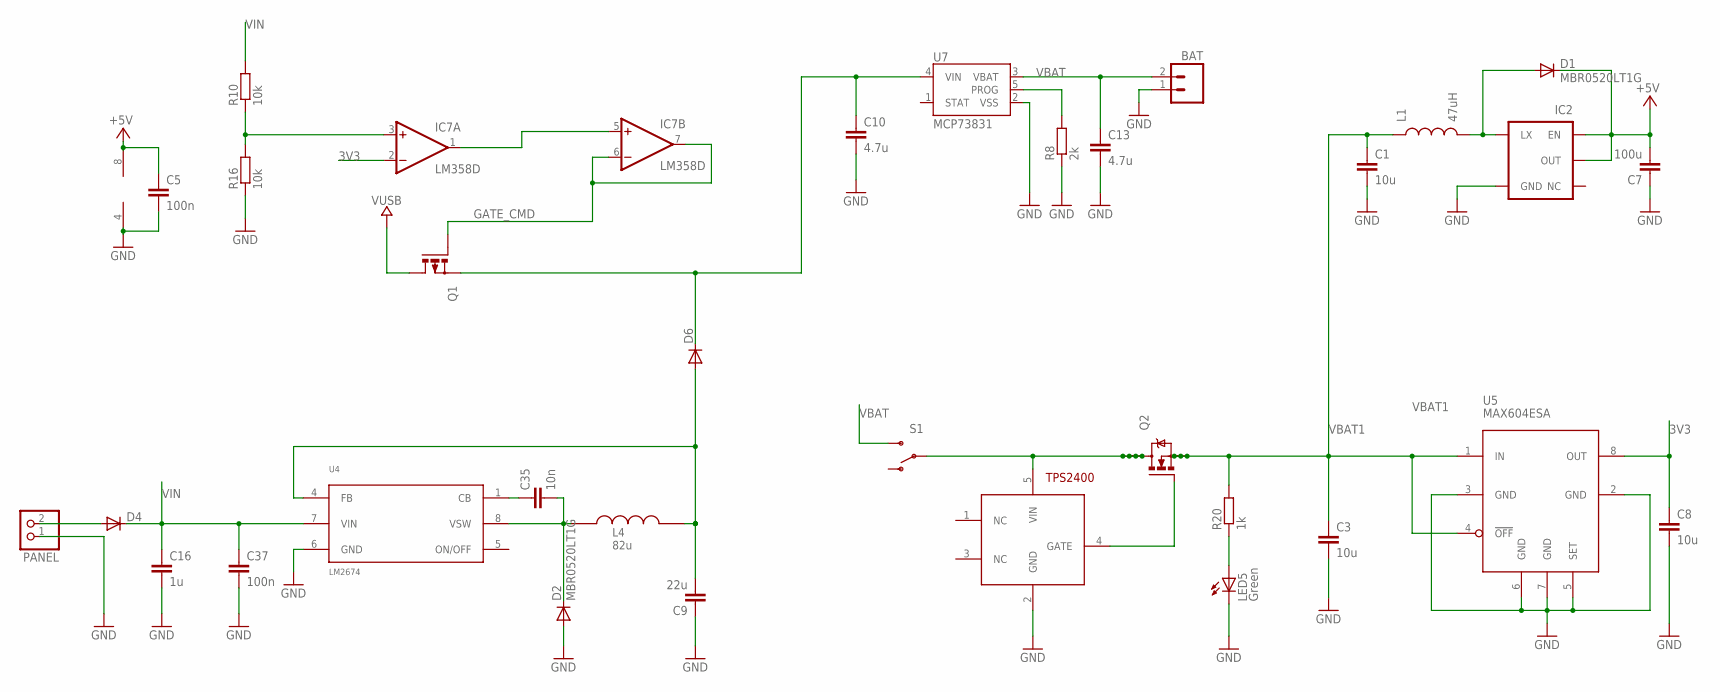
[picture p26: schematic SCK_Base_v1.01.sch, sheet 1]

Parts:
BAT: M02-JST-2MM-SMT; S2B-PH
C1, C3, C8: 10u; C0805
C5, C37: 100n; C0805
C7: 100u; C1206
C9: 22u; C1206
C10, C13: 4.7u; C0805
C16: 1u; C0805
C35: 10n; C0805
D1, D2: MBR0520LT1G; SOD123
D4, D6: DIODESMA-ALT; SMA-DIODE_ALT
IC2: V_REG_NCP1400SOT23-5; SOT23-5
IC7: LM358D; SO08
L1: 47uH; CR54
L4: 82u; SDR1006
LED5: Green; CHIP-LED0805
PANEL: PINHD-1X2; 1X02
Q1: P-MOSFET-SO8; SO-08
Q2: N-MOSFET-SO8S; SO-08
R8: 2k; R0805
R10, R16: 10k; R0805
R20: 1k; R0805
S1: SWITCH-SPST-SMD-A
U3: TPS2400; SOT23-5L
U4: LM2674; SO8
U5: MAX604ESA; SO-08
U7: MCP73831; SOT23-5

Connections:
3V3: C8.1, IC7.2 (-IN), U5.8 (OUT); also elsewhere on the board
+5V: C5.1, C7.2, D1.C, IC2.1 (EN), IC2.2 (OUT), IC7.8 (V+); also elsewhere on the board
GATE_CMD: IC7.6 (-IN), IC7.7 (OUT), Q1.4 (G)
GND: BAT.1, C1.2, C3.2, C5.2, C7.1, C8.2, C9.1, C10.2, C13.2, C16.2, C37.2, D2.A, IC2.4 (GND), IC7.4 (V-), LED5.C, PANEL.1, R8.1, R16.1, U3.2 (GND), U4.6 (GND), U5.2 (GND), U5.3 (GND), U5.5 (SET), U5.6 (GND), U5.7 (GND), U7.2 (VSS); also elsewhere on the board
unnamed: D4.A, PANEL.2
unnamed: IC7.3 (+IN), R10.1, R16.2
unnamed: IC7.1 (OUT), IC7.5 (+IN)
unnamed: C9.2, D6.A, L4.2, U4.4 (FB)
unnamed: R8.2, U7.5 (PROG)
unnamed: C10.1, D6.C, Q1.1 (S), Q1.2 (S), Q1.3 (S), U7.4 (VIN)
unnamed: LED5.A, R20.1
unnamed: Q2.4 (G), U3.4 (GATE)
unnamed: D1.A, IC2.5 (LX), L1.P$2 (2)
unnamed: C35.1, U4.1 (CB)
unnamed: C35.2, D2.C, L4.1, U4.8 (VSW)
VBAT: BAT.2, C13.1, S1.3 (S), U7.3 (VBAT)
VBAT1: C1.1, C3.1, L1.P$1 (1), Q2.1 (S), Q2.2 (S), Q2.3 (S), R20.2, U5.1 (IN), U5.4 (!OFF); also elsewhere on the board
VIN: C16.1, C37.1, D4.C, R10.2, U4.7 (VIN); also elsewhere on the board
VTPS: Q2.5 (D), Q2.6 (D), Q2.7 (D), Q2.8 (D), S1.2, U3.5 (VIN)
VUSB: Q1.5 (D), Q1.6 (D), Q1.7 (D), Q1.8 (D); also elsewhere on the board

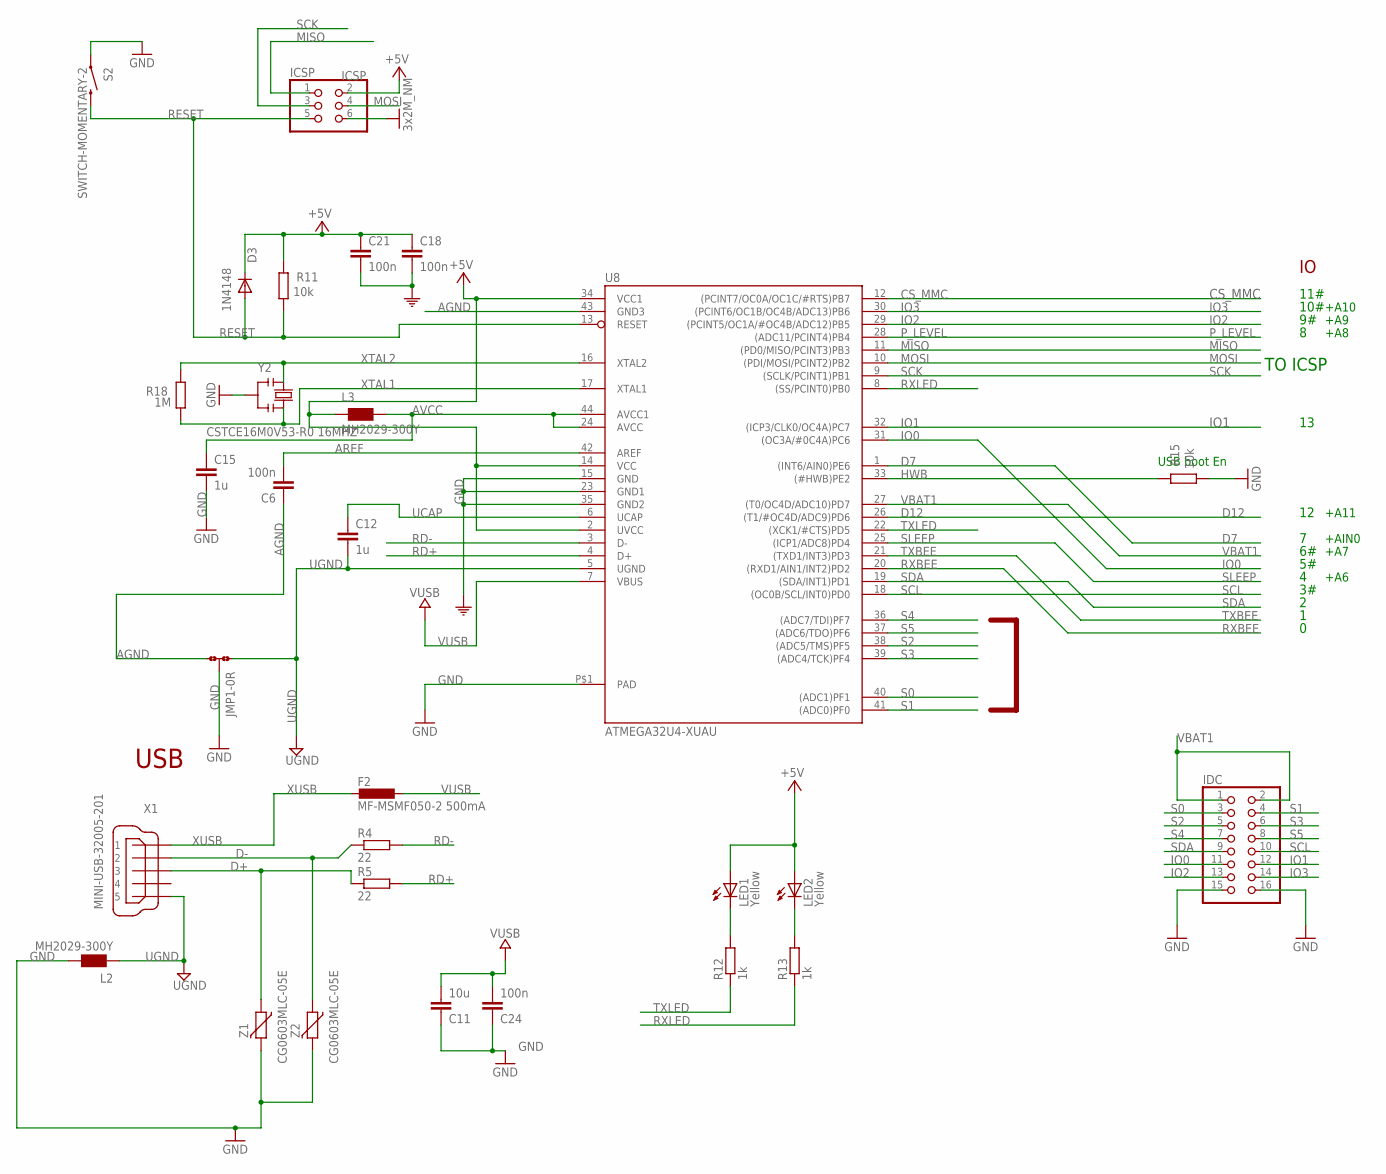
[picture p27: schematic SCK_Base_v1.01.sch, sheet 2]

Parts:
C6, C18, C21, C24: 100n; C0805
C11: 10u; C0805
C12, C15: 1u; C0805
D3: 1N4148; SOD123
F2: MF-MSMF050-2 500mA; L1812
ICSP: ICSP; 2X03
IDC: PINHD-2X8; 2X08
JMP1: 0R-JUMPC; C0R-JMP
L2, L3: MH2029-300Y; 0805
LED1, LED2: Yellow; CHIP-LED0805
R4, R5: 22; R0805
R11, R15: 10k; R0805
R12, R13: 1k; R0805
R18: 1M; R0805
S2: SWITCH-MOMENTARY-2; TACTILE_SWITCH_TALL
U8: ATMEGA32U4-XUAU; TQFP44-PAD
X1: MINI-USB-32005-201; 32005-201
Y2: CSTCE16M0V53-R0 16MHZ; RESONATOR
Z1, Z2: CG0603MLC-05E; CT/CN0603

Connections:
+5V: C18.1, C21.1, D3.C, ICSP.2, L3.1, LED1.A, LED2.A, R11.2, U8.2 (UVCC), U8.14 (VCC), U8.34 (VCC1); also elsewhere on the board
AGND: C6.1, JMP1.3, U8.43 (GND3)
AREF: C6.2, U8.42 (AREF)
AVCC: C15.1, L3.2, U8.24 (AVCC), U8.44 (AVCC1)
CS_MMC: U8.12 ((PCINT7/OC0A/OC1C/#RTS)PB7); also elsewhere on the board
D7: U8.1 ((INT6/AIN0)PE6)
D12: U8.26 ((T1/#OC4D/ADC9)PD6)
D+: R5.1, X1.3, Z1.1
D-: R4.1, X1.2, Z2.1
GND: C11.1, C15.2, C18.2, C21.2, C24.1, ICSP.6, IDC.15, IDC.16, JMP1.2, L2.2, R15.1, S2.A2 (1), U8.15 (GND), U8.23 (GND1), U8.35 (GND2), U8.P$1 (PAD), Y2.2, Z1.2, Z2.2; also elsewhere on the board
HWB: R15.2, U8.33 ((#HWB)PE2)
IO0: IDC.11, U8.31 ((OC3A/#0C4A)PC6)
IO1: IDC.12, U8.32 ((ICP3/CLK0/OC4A)PC7)
IO2: IDC.13, U8.29 ((PCINT5/OC1A/#OC4B/ADC12)PB5)
IO3: IDC.14, U8.30 ((PCINT6/OC1B/OC4B/ADC13)PB6)
MISO: ICSP.1, U8.11 ((PD0/MISO/PCINT3)PB3); also elsewhere on the board
MOSI: ICSP.4, U8.10 ((PDI/MOSI/PCINT2)PB2); also elsewhere on the board
unnamed: LED1.C, R12.2
unnamed: LED2.C, R13.2
P_LEVEL: U8.28 ((ADC11/PCINT4)PB4); also elsewhere on the board
RD+: R5.2, U8.4 (D+)
RD-: R4.2, U8.3 (D-)
RESET: D3.A, ICSP.5, R11.1, S2.B2 (2), U8.13 (RESET); also elsewhere on the board
RXBEE: U8.20 ((RXD1/AIN1/INT2)PD2); also elsewhere on the board
RXLED: R13.1, U8.8 ((SS/PCINT0)PB0)
S0: IDC.3, U8.40 ((ADC1)PF1)
S1: IDC.4, U8.41 ((ADC0)PF0)
S2: IDC.5, U8.38 ((ADC5/TMS)PF5)
S3: IDC.6, U8.39 ((ADC4/TCK)PF4)
S4: IDC.7, U8.36 ((ADC7/TDI)PF7)
S5: IDC.8, U8.37 ((ADC6/TDO)PF6)
SCK: ICSP.3, U8.9 ((SCLK/PCINT1)PB1); also elsewhere on the board
SCL: IDC.10, U8.18 ((OC0B/SCL/INT0)PD0); also elsewhere on the board
SDA: IDC.9, U8.19 ((SDA/INT1)PD1); also elsewhere on the board
SLEEP: U8.25 ((ICP1/ADC8)PD4); also elsewhere on the board
TXBEE: U8.21 ((TXD1/INT3)PD3); also elsewhere on the board
TXLED: R12.1, U8.22 ((XCK1/#CTS)PD5)
UCAP: C12.1, U8.6 (UCAP)
UGND: C12.2, JMP1.1, L2.1, U8.5 (UGND), X1.5
VBAT1: IDC.1, IDC.2, U8.27 ((T0/OC4D/ADC10)PD7); also elsewhere on the board
VUSB: C11.2, C24.2, F2.1, U8.7 (VBUS); also elsewhere on the board
XTAL1: R18.1, U8.17 (XTAL1), Y2.3
XTAL2: R18.2, U8.16 (XTAL2), Y2.1
XUSB: F2.2, X1.1

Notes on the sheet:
USB boot En
USB
TO ICSP
10#
11#
+A6
+A11
+A10
+A9
+A7
+A8
+AIN0

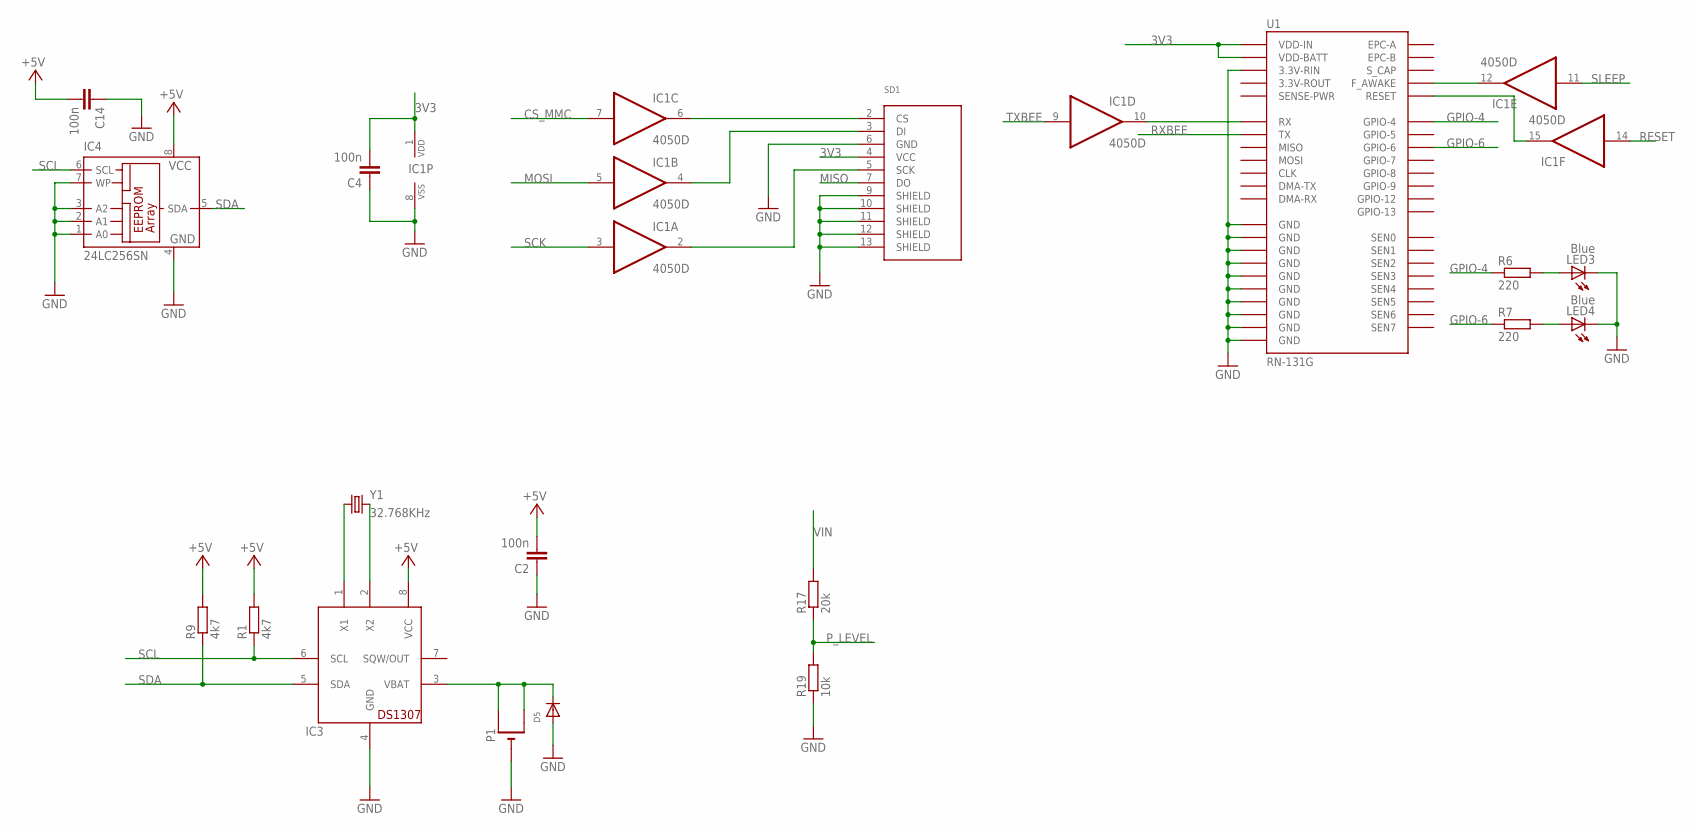
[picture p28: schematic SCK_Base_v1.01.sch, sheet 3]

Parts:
C2, C4, C14: 100n; C0805
D5: DIODESOD-323F; SOD-323F
IC1: 4050D; SO16
IC3: DS1307SOIC; SO08-SKINNYPADS
IC4: 24LC256SN; SO-08
LED3, LED4: Blue; CHIP-LED0805
P1: CR1220SMT; CR1220-SMD
R1, R9: 4k7; R0805
R6, R7: 220; R0805
R17: 20k; R0805
R19: 10k; R0805
SD1: SD_CARD_SOCKETDM3CS; DM3CS
U1: RN-131G
Y1: 32.768KHz; ABS10

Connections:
3V3: C4.2, IC1.1 (VDD), SD1.4 (VCC), U1.P$20 (VDD-BATT), U1.P$21 (VDD-IN); also elsewhere on the board
+5V: C2.2, C14.2, IC3.8 (VCC), IC4.8 (VCC), R1.2, R9.2; also elsewhere on the board
CS_MMC: IC1.7 (I); also elsewhere on the board
GND: C2.1, C4.1, C14.1, D5.A, IC1.8 (VSS), IC3.4 (GND), IC4.1 (A0), IC4.2 (A1), IC4.3 (A2), IC4.4 (GND), IC4.7 (WP), LED3.C, LED4.C, P1.-, R19.1, SD1.6 (GND), SD1.9 (SHIELD), SD1.10 (SHIELD), SD1.11 (SHIELD), SD1.12 (SHIELD), SD1.13 (SHIELD), U1.P$18 (3.3V-RIN), U1.P$19 (GND), U1.P$36 (GND), U1.P$37 (GND), U1.P$38 (GND), U1.P$39 (GND), U1.P$40 (GND), U1.P$41 (GND), U1.P$42 (GND), U1.P$43 (GND), U1.P$44 (GND); also elsewhere on the board
GPIO-4: R6.1, U1.P$29 (GPIO-4)
GPIO-6: R7.1, U1.P$27 (GPIO-6)
MISO: SD1.7 (DO); also elsewhere on the board
MOSI: IC1.5 (I); also elsewhere on the board
unnamed: IC1.10 (O), U1.P$12 (RX)
unnamed: LED4.A, R7.2
unnamed: LED3.A, R6.2
unnamed: IC1.6 (O), SD1.2 (CS)
unnamed: IC1.2 (O), SD1.5 (SCK)
unnamed: IC1.4 (O), SD1.3 (DI)
unnamed: IC1.12 (O), U1.P$9 (F_AWAKE)
unnamed: IC1.15 (O), U1.P$5 (RESET)
unnamed: IC3.1 (X1), Y1.1
unnamed: IC3.2 (X2), Y1.2
unnamed: D5.C, IC3.3 (VBAT), P1.+$1 (+), P1.+$2 (+1)
P_LEVEL: R17.1, R19.2; also elsewhere on the board
RESET: IC1.14 (I); also elsewhere on the board
RXBEE: U1.P$13 (TX); also elsewhere on the board
SCK: IC1.3 (I); also elsewhere on the board
SCL: IC3.6 (SCL), IC4.6 (SCL), R1.1; also elsewhere on the board
SDA: IC3.5 (SDA), IC4.5 (SDA), R9.1; also elsewhere on the board
SLEEP: IC1.11 (I); also elsewhere on the board
TXBEE: IC1.9 (I); also elsewhere on the board
VIN: R17.2; also elsewhere on the board

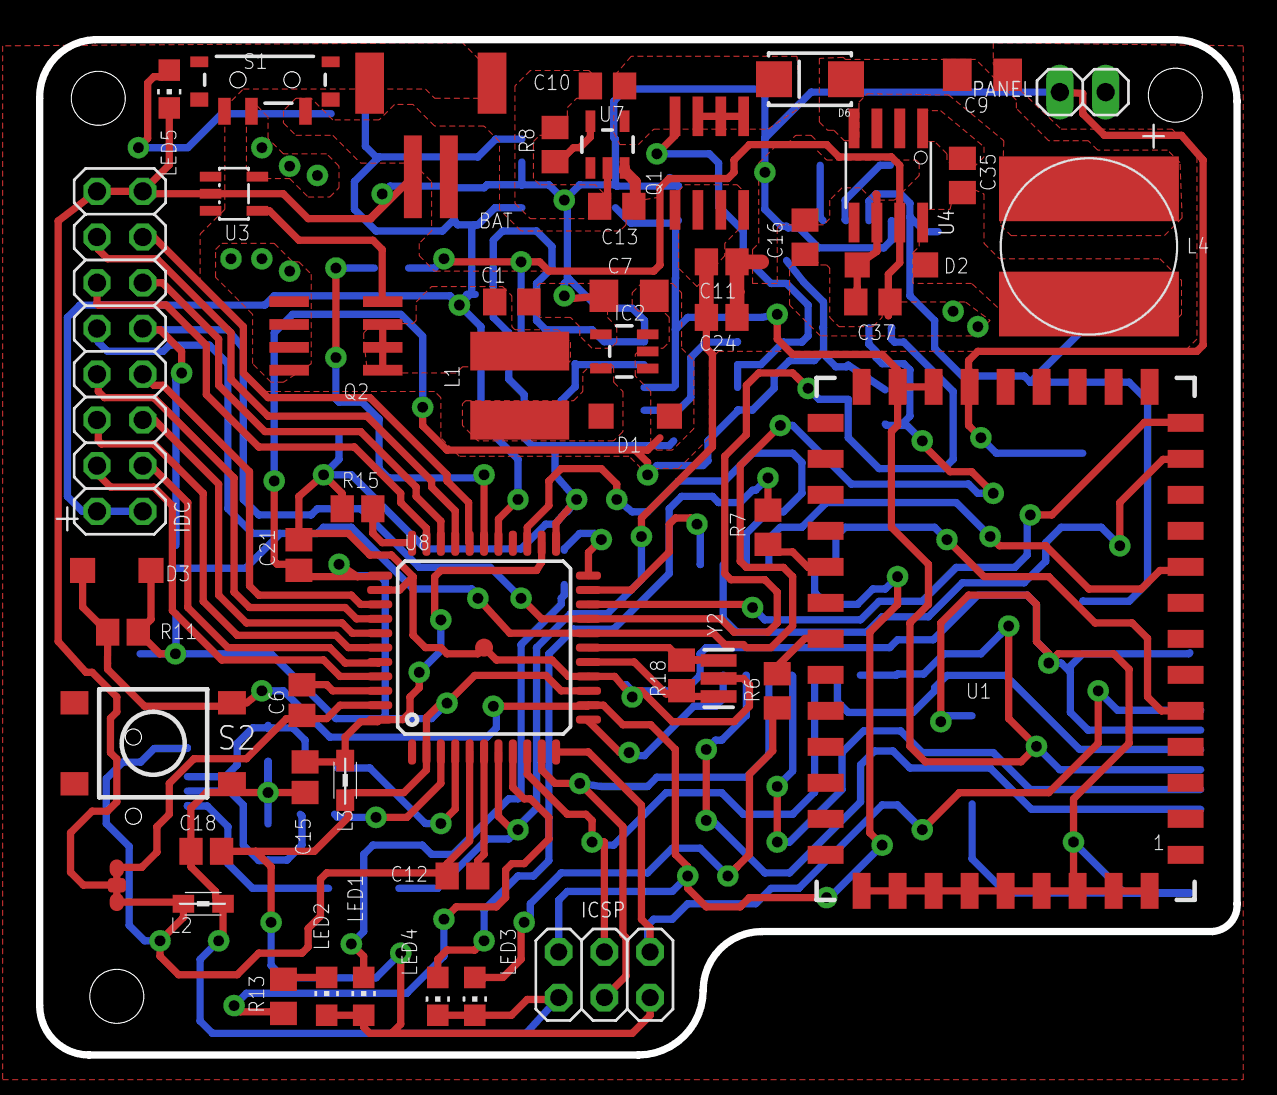
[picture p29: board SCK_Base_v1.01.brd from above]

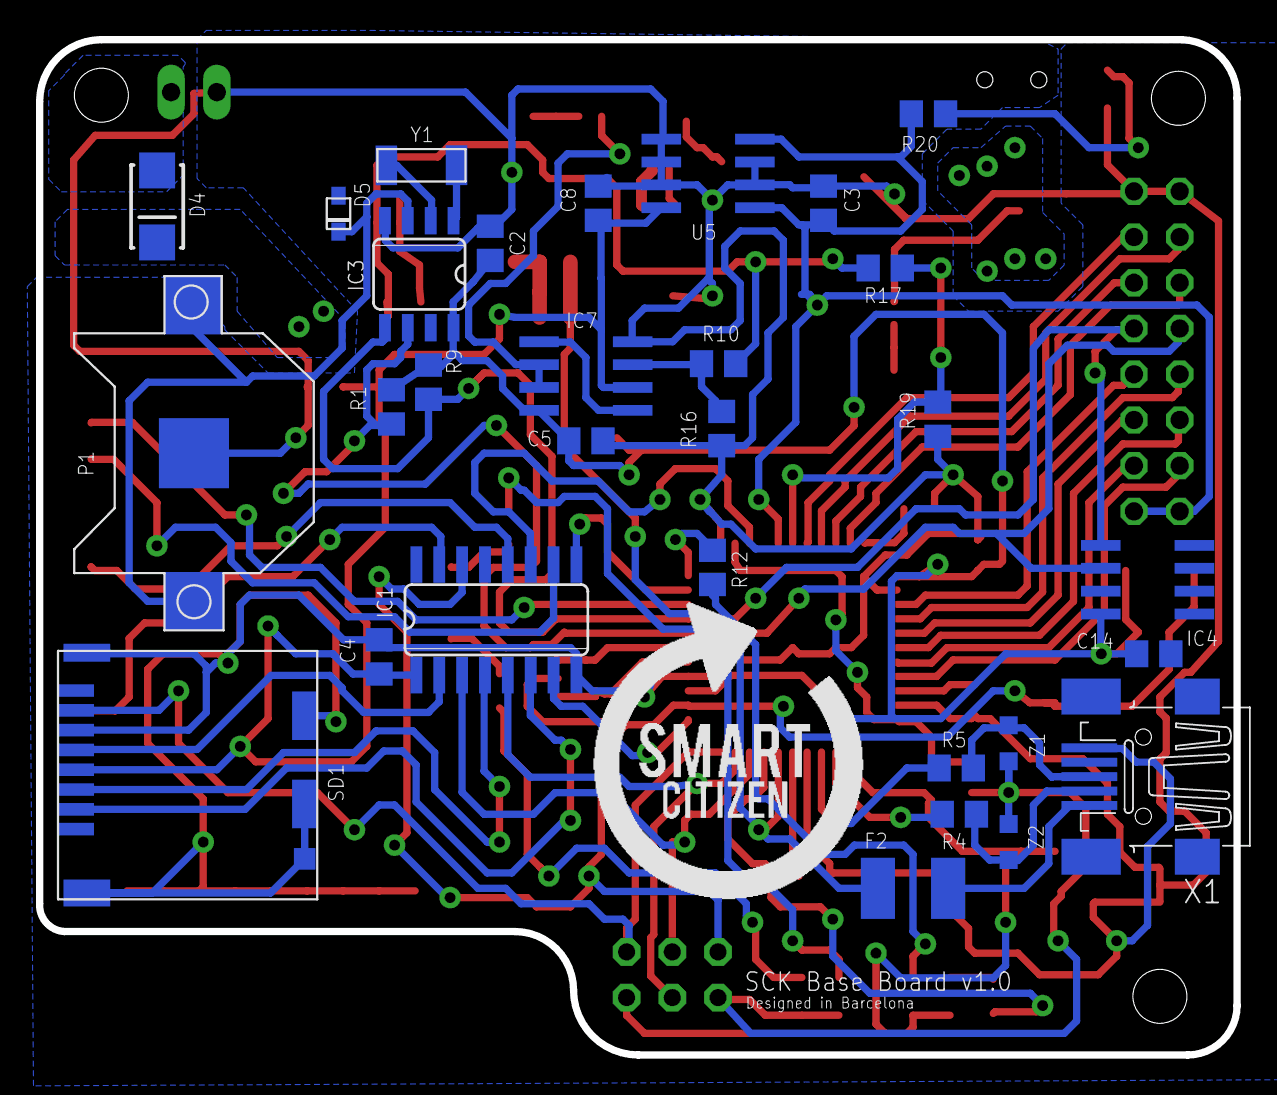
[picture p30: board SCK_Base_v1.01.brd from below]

Board: 2 copper layers, 66.5 x 56.4 mm, 81 parts (30 on the bottom side), 71 nets.

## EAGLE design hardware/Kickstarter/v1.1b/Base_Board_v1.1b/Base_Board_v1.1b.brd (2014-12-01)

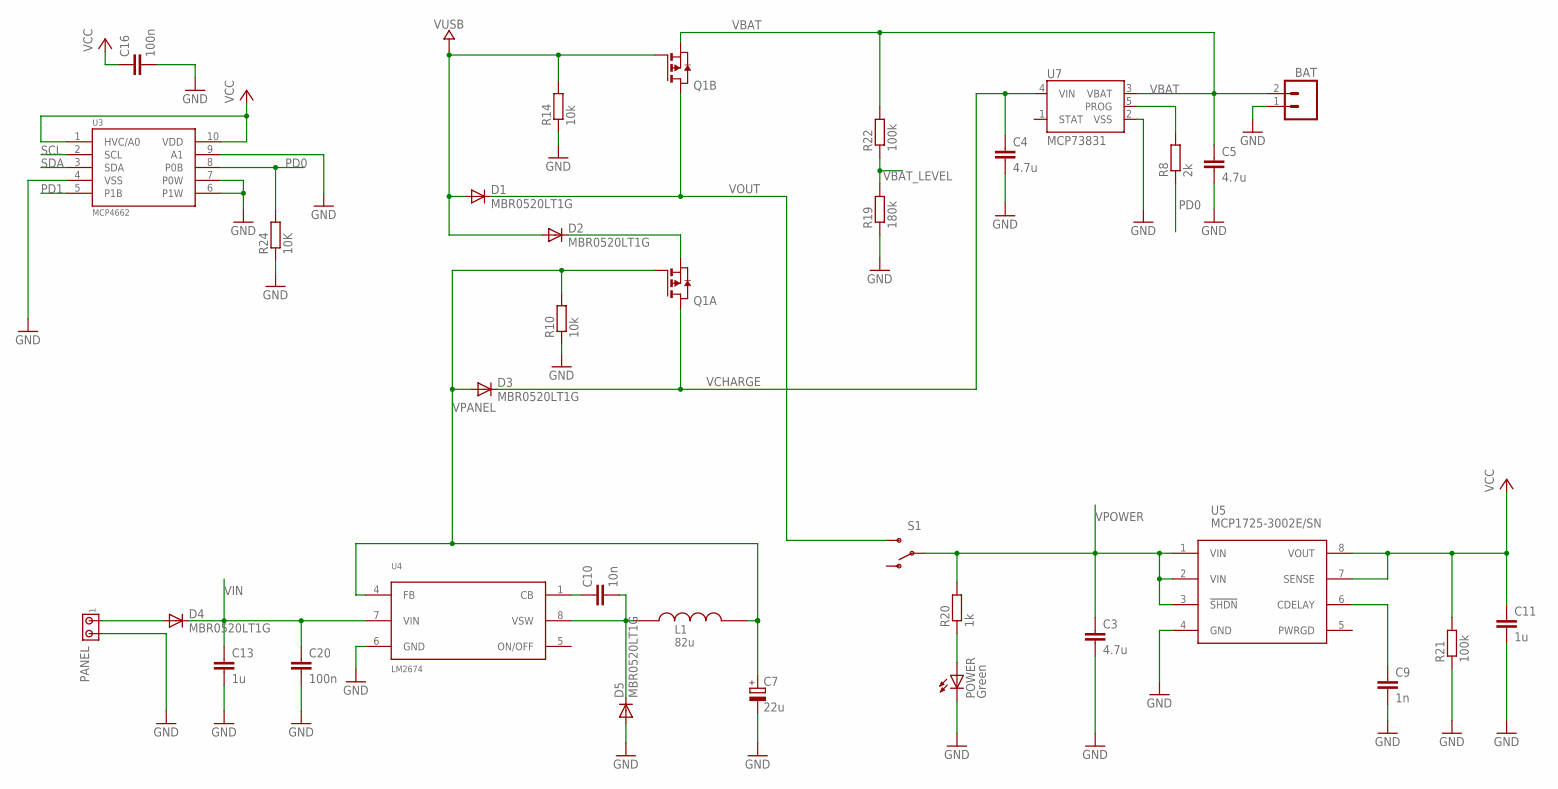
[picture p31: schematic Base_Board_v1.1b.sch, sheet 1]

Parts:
BAT: M02-JST-2MM-SMT; S2B-PH
C3, C4, C5: 4.7u; C0805
C7: 22u; SMC_A
C9: 1n; C0603K
C10: 10n; C0603K
C11, C13: 1u; C0805
C16, C20: 100n; C0603K
D1, D2, D3, D4, D5: MBR0520LT1G; SOD123
L1: 82u; SDR1006
PANEL: MTA02-100; 10X02MTA
POWER: Green; CHIP-LED0805
Q1: PMOS2SO8; SO8
R8: 2k; R0603
R10, R14: 10k; R0603
R19: 180k; R0603
R20: 1k; R0603
R21, R22: 100k; R0603
R24: 10K; R0603
S1: SWITCH-SPST-SMD-A
U3: MCP4662; MSOP10
U4: LM2674; SO8
U5: MCP1725-3002E/SN; SOIC8
U7: MCP73831; SOT23-5

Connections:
GND: BAT.1, C3.2, C4.2, C5.2, C7.-, C9.2, C11.2, C13.2, C16.2, C20.2, D5.A, PANEL.2, POWER.C, R10.1, R14.1, R19.1, R21.1, R24.1, U3.4 (VSS), U3.6 (P1W), U3.7 (P0W), U3.9 (A1), U4.6 (GND), U5.4 (GND), U7.2 (VSS); also elsewhere on the board
unnamed: D2.C, Q1.1 (S)
unnamed: D4.A, PANEL.1
unnamed: C9.1, U5.6 (CDELAY)
unnamed: R8.2, U7.5 (PROG)
unnamed: POWER.A, R20.1
unnamed: C10.1, U4.1 (CB)
unnamed: C10.2, D5.C, L1.1, U4.8 (VSW)
PD0: R8.1, R24.2, U3.8 (P0B)
PD1: U3.5 (P1B)
SCL: U3.2 (SCL); also elsewhere on the board
SDA: U3.3 (SDA); also elsewhere on the board
VBAT: BAT.2, C5.1, Q1.3 (S), R22.2, U7.3 (VBAT)
VBAT_LEVEL: R19.2, R22.1; also elsewhere on the board
VCC: C11.1, C16.1, R21.2, U3.1 (HVC/A0), U3.10 (VDD), U5.7 (SENSE), U5.8 (VOUT); also elsewhere on the board
VCHARGE: C4.1, D3.C, Q1.7 (D), Q1.8 (D), U7.4 (VIN)
VIN: C13.1, C20.1, D4.C, U4.7 (VIN); also elsewhere on the board
VOUT: D1.C, Q1.5 (D), Q1.6 (D), S1.3 (S)
VPANEL: C7.+, D3.A, L1.2, Q1.2 (G), R10.2, U4.4 (FB)
VPOWER: C3.1, R20.2, S1.2, U5.1 (VIN), U5.2 (VIN), U5.3 (!SHDN); also elsewhere on the board
VUSB: D1.A, D2.A, Q1.4 (G), R14.2; also elsewhere on the board

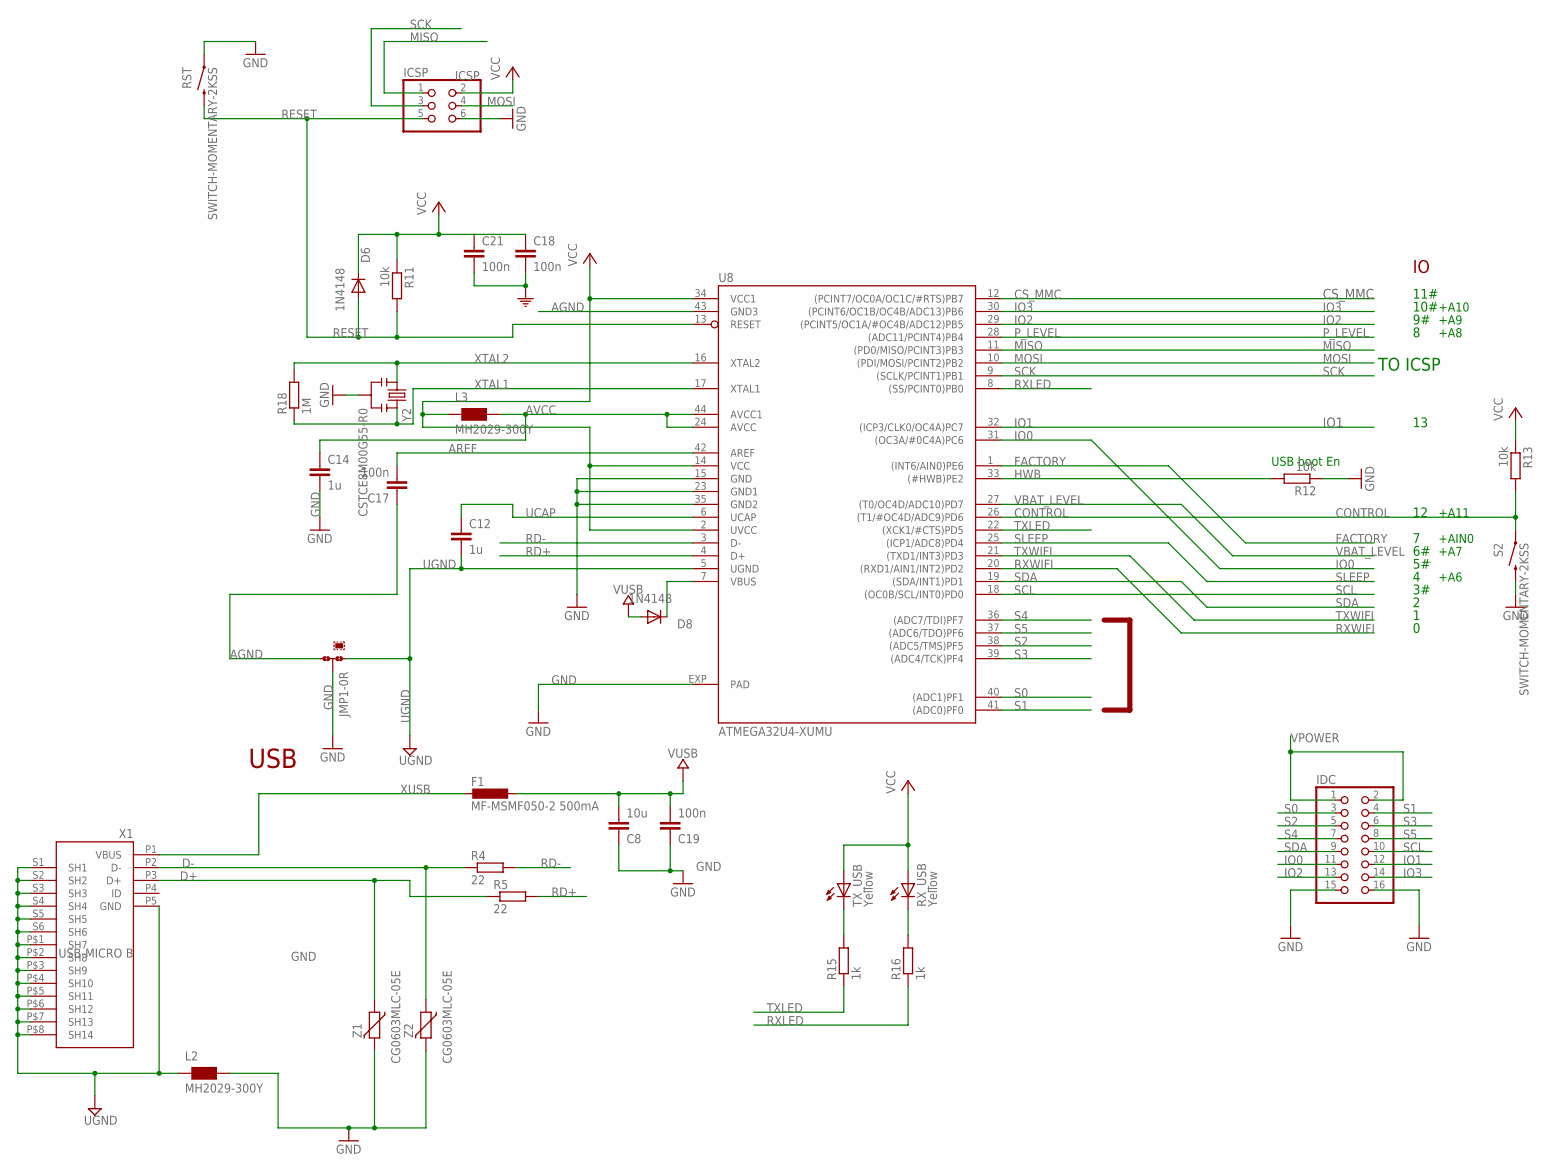
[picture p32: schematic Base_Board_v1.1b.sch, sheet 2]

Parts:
C8: 10u; C0805
C12, C14: 1u; C0805
C17, C18, C19, C21: 100n; C0603K
D6, D8: 1N4148; SOD323-W
F1: MF-MSMF050-2 500mA; L1812
ICSP: ICSP; 2X03
IDC: PINHD-2X8; 2X08
JMP1: 0R-JUMPC; C0R-JMP
L2, L3: MH2029-300Y; 0805
R4, R5: 22; R0603
R11, R12, R13: 10k; R0603
R15, R16: 1k; R0603
R18: 1M; R0603
RST: SWITCH-MOMENTARY-2KSS; KSS241G
RX_USB: Yellow; CHIP-LED0805
S2: SWITCH-MOMENTARY-2KSS; KSS241G
TX_USB: Yellow; CHIP-LED0805
U8: ATMEGA32U4-XUMU; QFN44ML7X7
X1: USB-MICRO B; CON2_USB_MICRO_B_AT
Y2: CSTCE8M00G55-R0
Z1, Z2: CG0603MLC-05E; CT/CN0603

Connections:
AGND: C17.1, JMP1.3, U8.43 (GND3)
AREF: C17.2, U8.42 (AREF)
AVCC: C14.1, L3.2, U8.24 (AVCC), U8.44 (AVCC1)
CONTROL: R13.2, S2.1, U8.26 ((T1/#OC4D/ADC9)PD6)
CS_MMC: U8.12 ((PCINT7/OC0A/OC1C/#RTS)PB7); also elsewhere on the board
D+: R5.1, X1.P3 (D+), Z1.1
D-: R4.1, X1.P2 (D-), Z2.1
FACTORY: U8.1 ((INT6/AIN0)PE6); also elsewhere on the board
GND: C8.1, C14.2, C18.2, C19.1, C21.2, ICSP.6, IDC.15, IDC.16, JMP1.2, L2.2, R12.1, RST.1, S2.2, U8.15 (GND), U8.23 (GND1), U8.35 (GND2), U8.EXP (PAD), Y2.2, Z1.2, Z2.2; also elsewhere on the board
GND1: L2.1, X1.P5 (GND), X1.P$1 (SH7), X1.P$2 (SH8), X1.P$3 (SH9), X1.P$4 (SH10), X1.P$5 (SH11), X1.P$6 (SH12), X1.P$7 (SH13), X1.P$8 (SH14), X1.S1 (SH1), X1.S2 (SH2), X1.S3 (SH3), X1.S4 (SH4), X1.S5 (SH5), X1.S6 (SH6)
HWB: R12.2, U8.33 ((#HWB)PE2)
IO0: IDC.11, U8.31 ((OC3A/#0C4A)PC6)
IO1: IDC.12, U8.32 ((ICP3/CLK0/OC4A)PC7)
IO2: IDC.13, U8.29 ((PCINT5/OC1A/#OC4B/ADC12)PB5)
IO3: IDC.14, U8.30 ((PCINT6/OC1B/OC4B/ADC13)PB6)
MISO: ICSP.1, U8.11 ((PD0/MISO/PCINT3)PB3); also elsewhere on the board
MOSI: ICSP.4, U8.10 ((PDI/MOSI/PCINT2)PB2); also elsewhere on the board
unnamed: R15.2, TX_USB.C
unnamed: R16.2, RX_USB.C
unnamed: D8.C, U8.7 (VBUS)
P_LEVEL: U8.28 ((ADC11/PCINT4)PB4); also elsewhere on the board
RD+: R5.2, U8.4 (D+)
RD-: R4.2, U8.3 (D-)
RESET: D6.A, ICSP.5, R11.2, RST.2, U8.13 (RESET); also elsewhere on the board
RXLED: R16.1, U8.8 ((SS/PCINT0)PB0)
RXWIFI: U8.20 ((RXD1/AIN1/INT2)PD2); also elsewhere on the board
S0: IDC.3, U8.40 ((ADC1)PF1)
S1: IDC.4, U8.41 ((ADC0)PF0)
S2: IDC.5, U8.38 ((ADC5/TMS)PF5)
S3: IDC.6, U8.39 ((ADC4/TCK)PF4)
S4: IDC.7, U8.36 ((ADC7/TDI)PF7)
S5: IDC.8, U8.37 ((ADC6/TDO)PF6)
SCK: ICSP.3, U8.9 ((SCLK/PCINT1)PB1); also elsewhere on the board
SCL: IDC.10, U8.18 ((OC0B/SCL/INT0)PD0); also elsewhere on the board
SDA: IDC.9, U8.19 ((SDA/INT1)PD1); also elsewhere on the board
SLEEP: U8.25 ((ICP1/ADC8)PD4); also elsewhere on the board
TXLED: R15.1, U8.22 ((XCK1/#CTS)PD5)
TXWIFI: U8.21 ((TXD1/INT3)PD3); also elsewhere on the board
UCAP: C12.1, U8.6 (UCAP)
UGND: C12.2, JMP1.1, U8.5 (UGND)
VBAT_LEVEL: U8.27 ((T0/OC4D/ADC10)PD7); also elsewhere on the board
VCC: C18.1, C21.1, D6.C, ICSP.2, L3.1, R11.1, R13.1, RX_USB.A, TX_USB.A, U8.2 (UVCC), U8.14 (VCC), U8.34 (VCC1); also elsewhere on the board
VPOWER: IDC.1, IDC.2; also elsewhere on the board
VUSB: C8.2, C19.2, D8.A, F1.1; also elsewhere on the board
XTAL1: R18.1, U8.17 (XTAL1), Y2.3
XTAL2: R18.2, U8.16 (XTAL2), Y2.1
XUSB: F1.2, X1.P1 (VBUS)

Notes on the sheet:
USB boot En
USB
TO ICSP
10#
11#
+A6
+A11
+A10
+A9
+A7
+A8
+AIN0

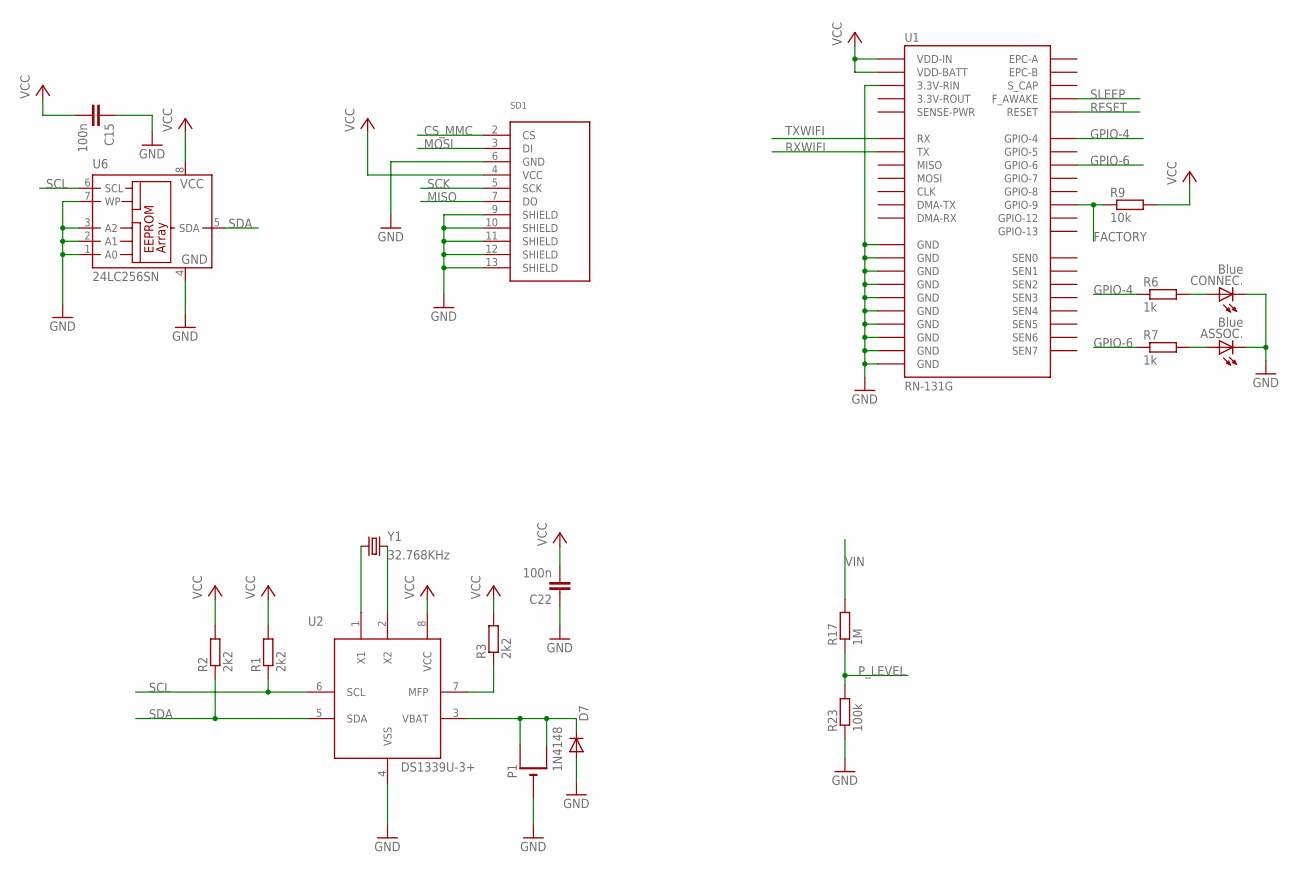
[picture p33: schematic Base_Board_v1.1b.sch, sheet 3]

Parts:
ASSOC.: Blue; CHIP-LED0805
C15, C22: 100n; C0603K
CONNEC.: Blue; CHIP-LED0805
D7: 1N4148; SOD323-W
P1: CR1220SMT; CR1220-SMD
R1, R2, R3: 2k2; R0603
R6, R7: 1k; R0603
R9: 10k; R0603
R17: 1M; R0603
R23: 100k; R0603
SD1: SD_CARD_SOCKETDM3CS; DM3CS
U1: RN-131G
U2: DS1339U-3+; MSOP-8
U6: 24LC256SN; SO-08
Y1: 32.768KHz; ABS10

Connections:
CS_MMC: SD1.2 (CS); also elsewhere on the board
FACTORY: R9.1, U1.P$24 (GPIO-9); also elsewhere on the board
GND: ASSOC..C, C15.1, C22.1, CONNEC..C, D7.A, P1.-, R23.1, SD1.6 (GND), SD1.9 (SHIELD), SD1.10 (SHIELD), SD1.11 (SHIELD), SD1.12 (SHIELD), SD1.13 (SHIELD), U1.P$18 (3.3V-RIN), U1.P$19 (GND), U1.P$36 (GND), U1.P$37 (GND), U1.P$38 (GND), U1.P$39 (GND), U1.P$40 (GND), U1.P$41 (GND), U1.P$42 (GND), U1.P$43 (GND), U1.P$44 (GND), U2.4 (VSS), U6.1 (A0), U6.2 (A1), U6.3 (A2), U6.4 (GND), U6.7 (WP); also elsewhere on the board
GPIO-4: R6.1, U1.P$29 (GPIO-4)
GPIO-6: R7.1, U1.P$27 (GPIO-6)
MISO: SD1.7 (DO); also elsewhere on the board
MOSI: SD1.3 (DI); also elsewhere on the board
unnamed: ASSOC..A, R7.2
unnamed: R3.1, U2.7 (MFP)
unnamed: CONNEC..A, R6.2
unnamed: U2.1 (X1), Y1.1
unnamed: U2.2 (X2), Y1.2
unnamed: D7.C, P1.+$1 (+), P1.+$2 (+1), U2.3 (VBAT)
P_LEVEL: R17.1, R23.2; also elsewhere on the board
RESET: U1.P$5 (RESET); also elsewhere on the board
RXWIFI: U1.P$13 (TX); also elsewhere on the board
SCK: SD1.5 (SCK); also elsewhere on the board
SCL: R1.1, U2.6 (SCL), U6.6 (SCL); also elsewhere on the board
SDA: R2.1, U2.5 (SDA), U6.5 (SDA); also elsewhere on the board
SLEEP: U1.P$9 (F_AWAKE); also elsewhere on the board
TXWIFI: U1.P$12 (RX); also elsewhere on the board
VCC: C15.2, C22.2, R1.2, R2.2, R3.2, R9.2, SD1.4 (VCC), U1.P$20 (VDD-BATT), U1.P$21 (VDD-IN), U2.8 (VCC), U6.8 (VCC); also elsewhere on the board
VIN: R17.2; also elsewhere on the board

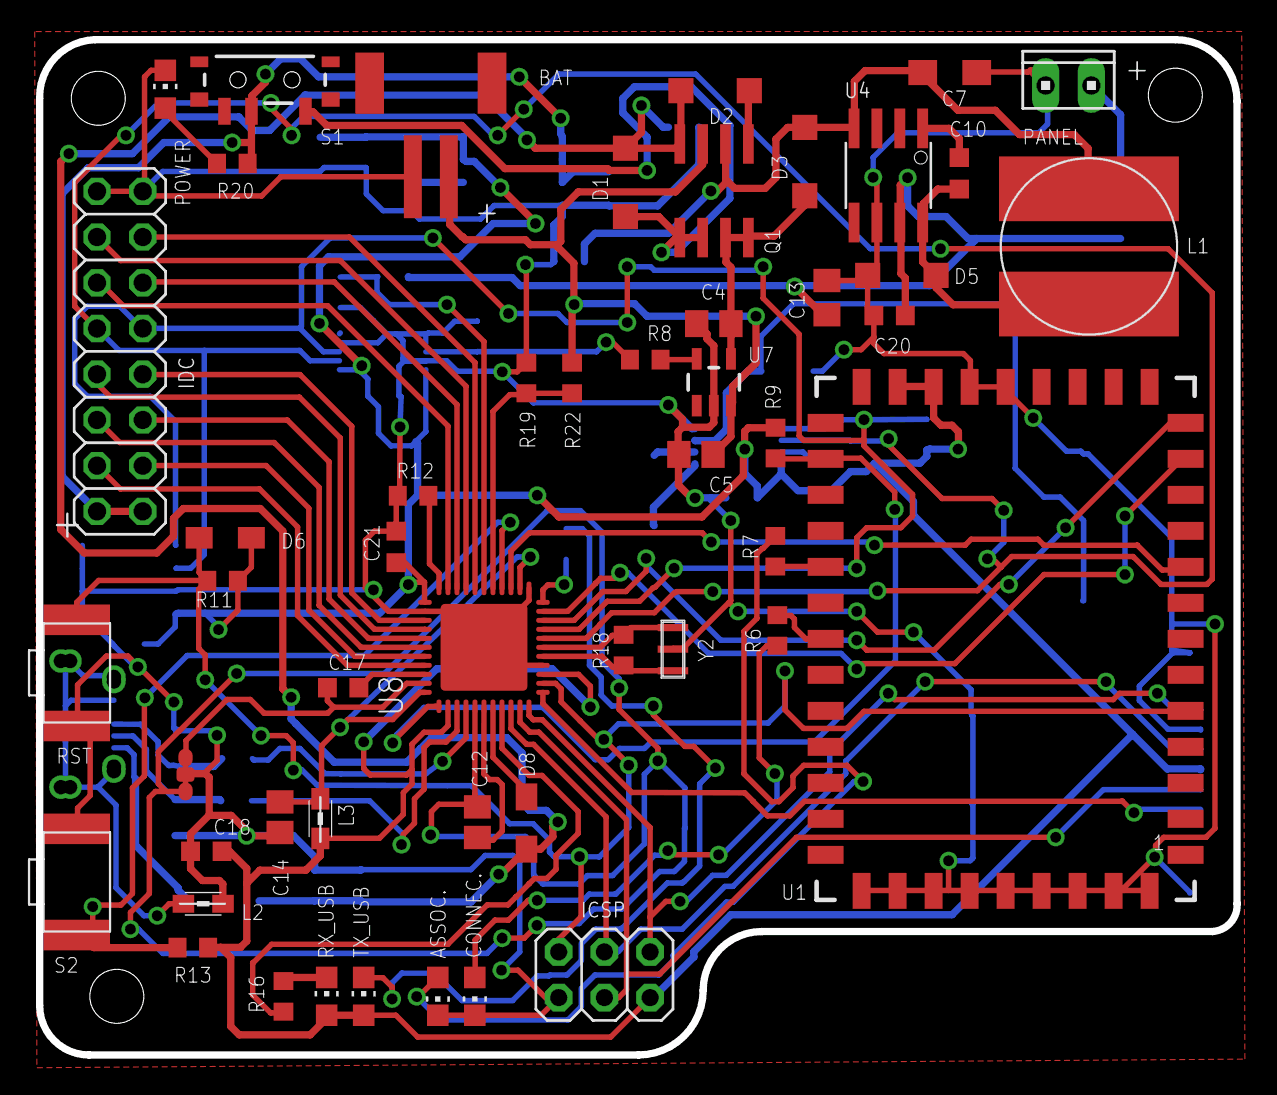
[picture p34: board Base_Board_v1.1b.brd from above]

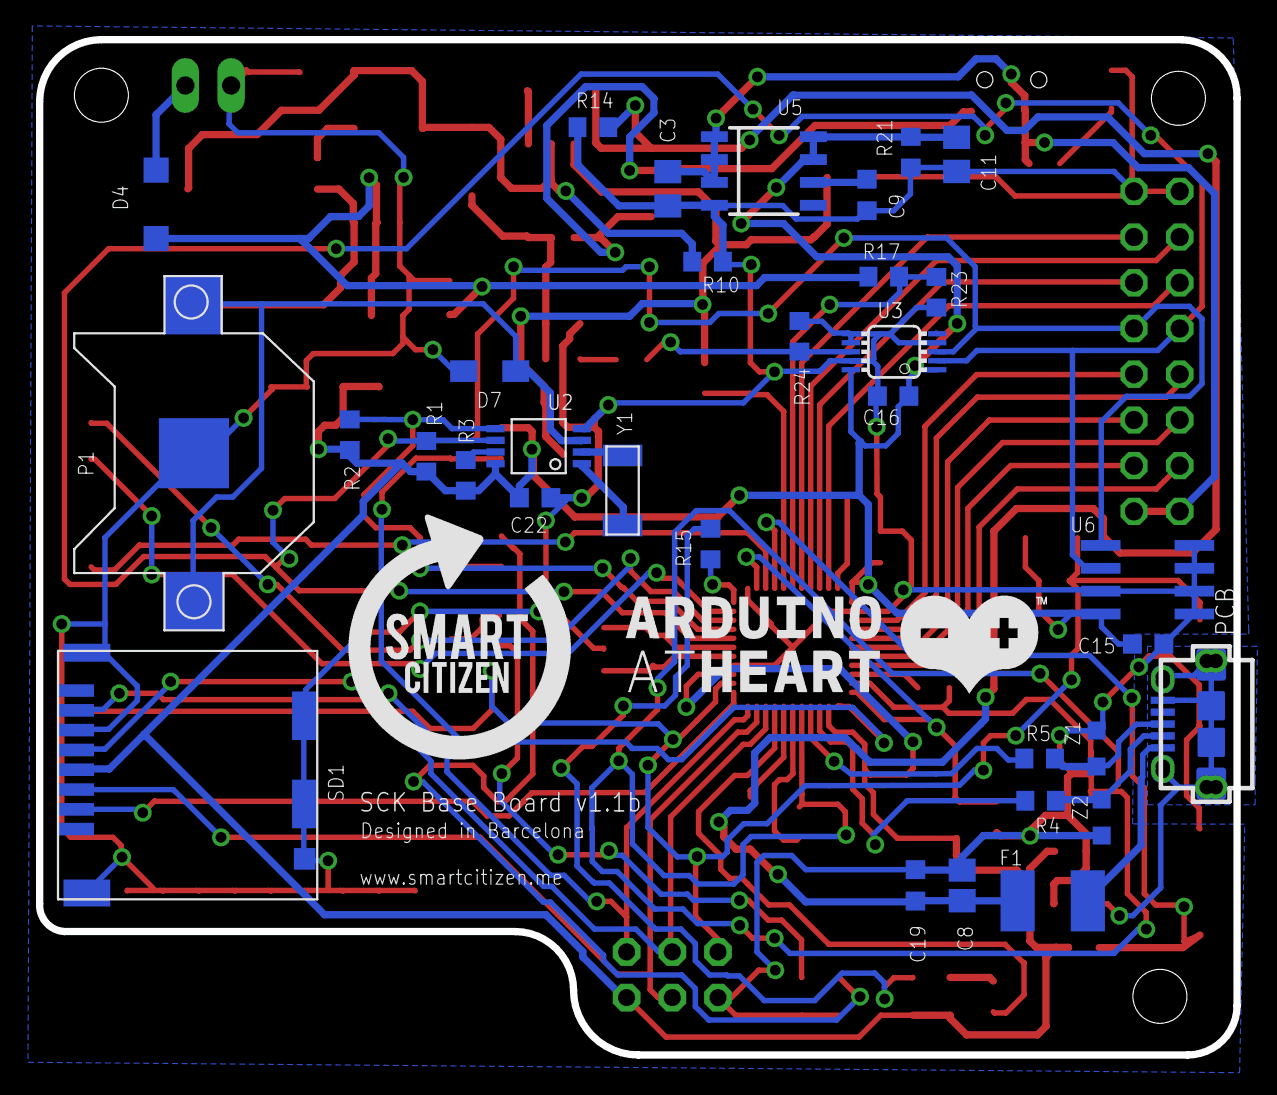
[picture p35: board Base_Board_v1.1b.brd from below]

Board: 2 copper layers, 66.5 x 56.4 mm, 84 parts (33 on the bottom side), 68 nets.

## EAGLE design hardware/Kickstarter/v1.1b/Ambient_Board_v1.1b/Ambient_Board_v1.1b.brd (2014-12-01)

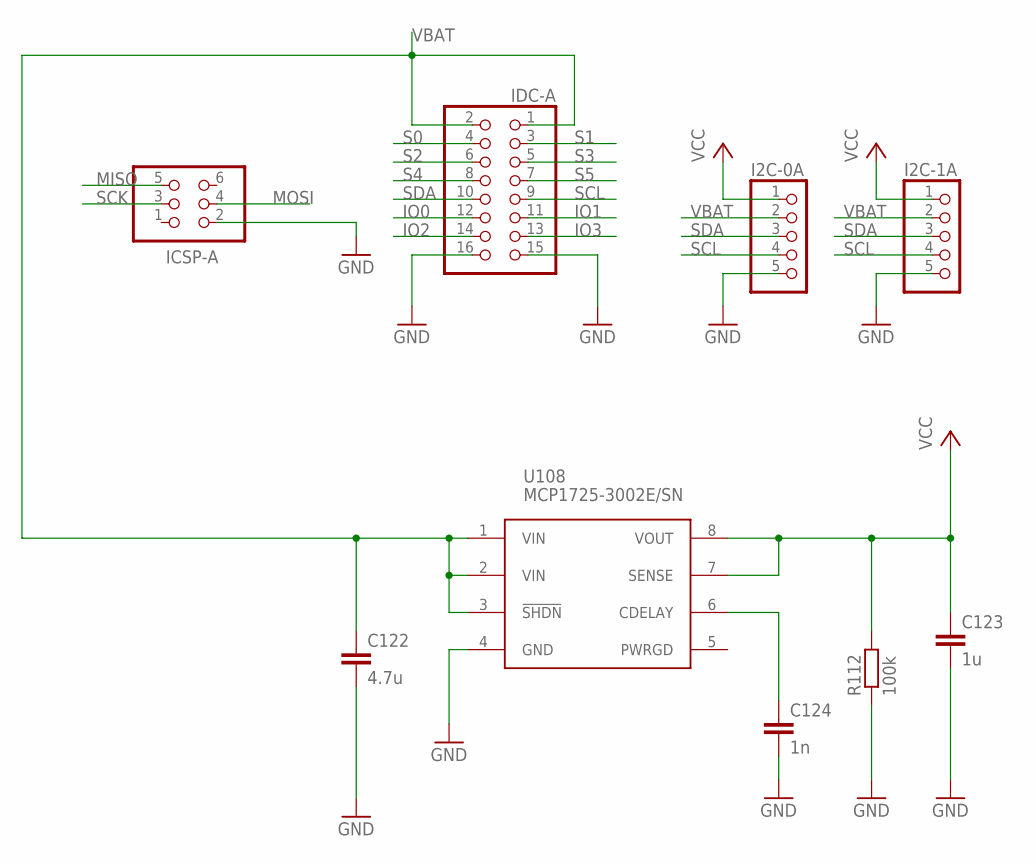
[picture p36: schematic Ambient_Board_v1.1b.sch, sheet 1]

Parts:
C122: 4.7u; C0805
C123: 1u; C0805
C124: 1n; C0603K
I2C-0A, I2C-1A: PINHD-1X5; 1X05
ICSP-A: ICSP-A; 2X03
IDC-A: PINHD-2X8; 2X08
R112: 100k; R0603
U108: MCP1725-3002E/SN; SOIC8

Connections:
GND: C122.2, C123.2, C124.2, I2C-0A.5, I2C-1A.5, ICSP-A.2, IDC-A.15, IDC-A.16, R112.1, U108.4 (GND); also elsewhere on the board
IO0: IDC-A.12; also elsewhere on the board
IO1: IDC-A.11; also elsewhere on the board
IO2: IDC-A.14; also elsewhere on the board
IO3: IDC-A.13; also elsewhere on the board
MISO: ICSP-A.5
MOSI: ICSP-A.4
unnamed: C124.1, U108.6 (CDELAY)
S0: IDC-A.4; also elsewhere on the board
S1: IDC-A.3; also elsewhere on the board
S2: IDC-A.6; also elsewhere on the board
S3: IDC-A.5; also elsewhere on the board
S4: IDC-A.8; also elsewhere on the board
S5: IDC-A.7
SCK: ICSP-A.3
SCL: I2C-0A.4, I2C-1A.4, IDC-A.9; also elsewhere on the board
SDA: I2C-0A.3, I2C-1A.3, IDC-A.10; also elsewhere on the board
VBAT: C122.1, I2C-0A.2, I2C-1A.2, IDC-A.1, IDC-A.2, U108.1 (VIN), U108.2 (VIN), U108.3 (!SHDN); also elsewhere on the board
VCC: C123.1, I2C-0A.1, I2C-1A.1, R112.2, U108.7 (SENSE), U108.8 (VOUT); also elsewhere on the board

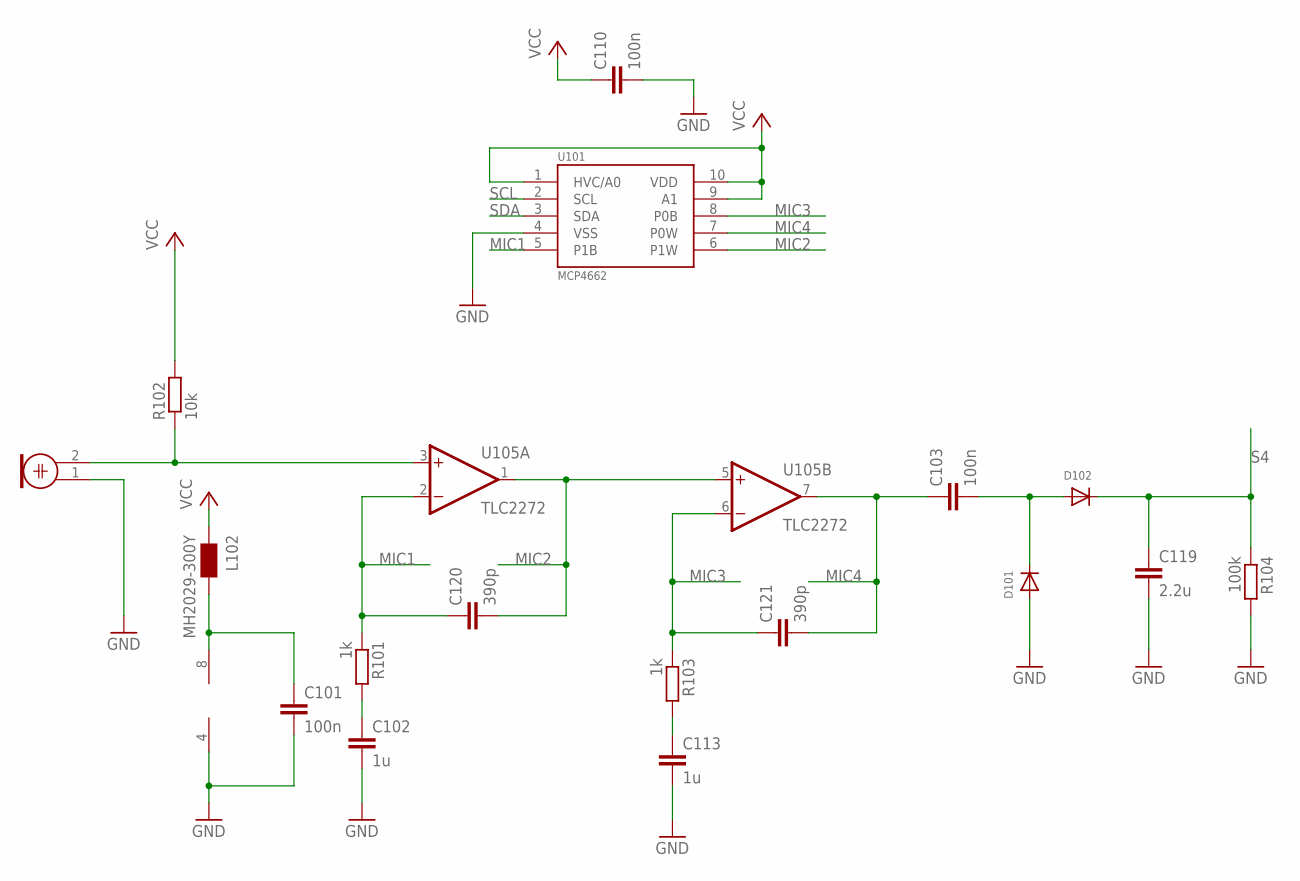
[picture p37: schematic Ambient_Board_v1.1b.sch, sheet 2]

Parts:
C101, C103, C110: 100n; C0603
C102, C113: 1u; C0805
C119: 2.2u; C0805
C120, C121: 390p; C0603
D101, D102: DIODESOD-323F; SOD-323F
L102: MH2029-300Y; 0805
M101: POM-3044P-R; WM-63PR
R101, R103: 1k; R0603
R102: 10k; R0603
R104: 100k; R0603
U101: MCP4662; MSOP10
U105: TLC2272; SO08

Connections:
GND: C101.2, C102.2, C110.2, C113.2, C119.2, D101.A, M101.1, R104.2, U101.4 (VSS), U105.4 (V-); also elsewhere on the board
MIC1: C120.1, R101.1, U101.5 (P1B), U105.2 (-IN)
MIC2: C120.2, U101.6 (P1W), U105.1 (OUT), U105.5 (+IN)
MIC3: C121.1, R103.1, U101.8 (P0B), U105.6 (-IN)
MIC4: C103.1, C121.2, U101.7 (P0W), U105.7 (OUT)
unnamed: M101.2, R102.1, U105.3 (+IN)
unnamed: C102.1, R101.2
unnamed: C103.2, D101.C, D102.A
unnamed: C101.1, L102.2, U105.8 (V+)
unnamed: C113.1, R103.2
S4: C119.1, D102.C, R104.1; also elsewhere on the board
SCL: U101.2 (SCL); also elsewhere on the board
SDA: U101.3 (SDA); also elsewhere on the board
VCC: C110.1, L102.1, R102.2, U101.1 (HVC/A0), U101.9 (A1), U101.10 (VDD); also elsewhere on the board


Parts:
C106, C107: 100n; C0603
C111, C112, C114: 1u; C0805
C115, C117, C118: 4.7u; C0805
L101: MH2029-300Y; 0805
R105: 39; R0603
R106: 10; R0603
R107, R108, R109: 12k; R0603
R110: 68k; R0603
R111: 560k; R0603
S101: MICS4514; MICS_SMD
U102, U103, U104: MCP1824; SOT23-5L
U106: TLC2272; SO08
U107: MCP4462; TSSOP14

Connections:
ADJ_0: R107.1, U102.4 (ADJ), U107.9 (P0W)
ADJ_1: R108.1, U103.4 (ADJ), U107.8 (P1W)
GND: C106.2, C107.2, C111.2, C112.2, C114.2, C115.2, C117.2, C118.2, R105.1, R106.1, R107.2, R108.2, R109.2, R111.1, U102.2 (GND), U103.2 (GND), U104.2 (GND), U106.4 (V-), U107.3 (HVC/A0), U107.6 (VSS), U107.14 (P2W); also elsewhere on the board
IO0: U102.3 (!SHDN); also elsewhere on the board
IO1: U103.3 (!SHDN); also elsewhere on the board
IO2: R111.2, U107.1 (P3W); also elsewhere on the board
IO3: U104.3 (!SHDN); also elsewhere on the board
unnamed: C107.1, L101.2, U106.8 (V+)
unnamed: R109.1, R110.2, U104.4 (ADJ)
S0: U106.1 (OUT), U106.2 (-IN); also elsewhere on the board
S0R: S101.D (4), U106.3 (+IN), U107.13 (P2B)
S1: U106.6 (-IN), U106.7 (OUT); also elsewhere on the board
S1R: S101.B (4), U106.5 (+IN), U107.2 (P3B)
S2: R106.2, S101.C (1); also elsewhere on the board
S3: R105.2, S101.A (1); also elsewhere on the board
SCL: U107.4 (SCL); also elsewhere on the board
SDA: U107.5 (SDA); also elsewhere on the board
VBAT: C115.1, C117.1, C118.1, U102.1 (VIN), U103.1 (VIN), U104.1 (VIN); also elsewhere on the board
VCC: C106.1, L101.1, U107.11 (A1), U107.12 (VDD); also elsewhere on the board
VMICS: C114.1, R110.1, S101.G (2), S101.J (2), U104.5 (VOUT)
VOUT_0: C111.1, S101.F (3), U102.5 (VOUT), U107.10 (P0B)
VOUT_1: C112.1, S101.H (3), U103.5 (VOUT), U107.7 (P1B)


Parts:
C104, C108, C109, C125: 100n; C0603
L104, L105, L106: MH2029-300Y; 0805
S102: SHT21; DFN300X300X110-7N
S103: BH1730FVC; WSOF6
U109: ADXL345; LGA14

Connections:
GND: C104.2, C108.2, C109.2, C125.2, S102.2 (VSS), S102.7 (EPAD), S103.2 (INT), S103.3 (GND), U109.2 (GND), U109.4 (GND1), U109.5 (GND2), U109.10 (GND3), U109.12 (SDO); also elsewhere on the board
unnamed: C125.1, L106.2, U109.1 (VDD), U109.6 (VSS), U109.7 (CS)
unnamed: C108.1, L105.2, S102.5 (VDD)
unnamed: C104.1, C109.1, L104.2, S103.1 (VCC), S103.5 (DVI)
SCL: S102.6 (SCL), S103.6 (SCL), U109.14 (SCL); also elsewhere on the board
SDA: S102.1 (SDA), S103.4 (SDA), U109.13 (SDA); also elsewhere on the board
VCC: L104.1, L105.1, L106.1; also elsewhere on the board



Board: 2 copper layers, 66.5 x 56.4 mm, 59 parts (2 on the bottom side), 36 nets.

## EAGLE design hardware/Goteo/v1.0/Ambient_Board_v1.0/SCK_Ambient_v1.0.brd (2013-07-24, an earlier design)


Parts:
I2C_0, I2C_1: PINHD-1X5; 1X05
ICSP: ICSP; 2X03
IDC: PINHD-2X8; 2X08

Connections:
+5V: I2C_0.1, I2C_1.1, ICSP.6; also elsewhere on the board
GND: I2C_0.5, I2C_1.5, ICSP.2, IDC.15, IDC.16; also elsewhere on the board
IO0: IDC.12; also elsewhere on the board
IO1: IDC.11; also elsewhere on the board
IO2: IDC.14; also elsewhere on the board
IO3: IDC.13; also elsewhere on the board
MISO: ICSP.5
MOSI: ICSP.4
S0: IDC.4; also elsewhere on the board
S1: IDC.3; also elsewhere on the board
S2: IDC.6; also elsewhere on the board
S3: IDC.5; also elsewhere on the board
S4: IDC.8; also elsewhere on the board
S5: IDC.7; also elsewhere on the board
SCK: ICSP.3
SCL: I2C_0.4, I2C_1.4, IDC.9; also elsewhere on the board
SDA: I2C_0.3, I2C_1.3, IDC.10; also elsewhere on the board
VBAT1: I2C_0.2, I2C_1.2, IDC.1, IDC.2; also elsewhere on the board


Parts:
C1, C3: 100n; C0805
C2, C4, C19: 2.2u; C0805
C5: 10p; C0805
D1, D2: DIODESOD-123; SOD-123
L2: MH2029-300Y; 0805
M1: ELECTRET_MICROPHON-WM-61A; WM-61A
PH1: A1050_09; T0-46-A10XX
R1: 4K7; R0805
R2: 10K; R0805
R3: 560k; R0805
R4: 100K; R0805
R12: 2K2; R0805
U4: TL082D; SO08

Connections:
+5V: L2.1, PH1.1; also elsewhere on the board
GND: C1.2, C2.2, C4.2, D1.A, M1.1, R4.2, R12.2, U4.4 (V-); also elsewhere on the board
unnamed: C19.1, M1.2, R2.1
unnamed: C2.1, R1.2
unnamed: C3.2, D1.C, D2.A
unnamed: C5.1, R1.1, R3.2, U4.2 (-IN)
unnamed: C3.1, C5.2, R3.1, U4.1 (OUT)
unnamed: C1.1, L2.2, U4.8 (V+)
unnamed: PH1.2, R12.1, U4.5 (+IN)
unnamed: C19.2, U4.3 (+IN)
S4: C4.1, D2.C, R4.1; also elsewhere on the board
S5: U4.6 (-IN), U4.7 (OUT); also elsewhere on the board
VOUT_2: R2.2; also elsewhere on the board


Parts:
C6, C10, C18: 100n; C0805
C7, C8, C11, C12, C14, C15: 10u; C0805
C9, C13, C16: 100p; C0805
L1: MH2029-300Y; 0805
R5, R6: 10; R0805
R7, R8: 82k; R0805
R9: 180K; R0805
R10: 200K; R0805
R13: 560k; R0805
S1: MICS-5525; E2V
S2: MICS-2710; E2V
U1, U6: MCP4662; MSOP10
U2, U3, U5: TC1071; SOT23-5L
U7: TL082D; SO08

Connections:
+5V: C6.1, C10.1, L1.1, S1.2, U1.1 (HVC/A0), U1.9 (A1), U1.10 (VDD), U6.9 (A1), U6.10 (VDD); also elsewhere on the board
ADJ_0: C9.1, R7.1, U2.4 (ADJ), U6.7 (P0W)
ADJ_1: C13.1, R8.1, U3.4 (ADJ), U6.6 (P1W)
ADJ_2: C16.1, R9.1, R10.2, U5.4 (ADJ)
GND: C6.2, C7.2, C8.2, C9.2, C10.2, C11.2, C12.2, C13.2, C14.2, C15.2, C16.2, C18.2, R5.1, R6.1, R7.2, R8.2, R9.2, R13.1, U1.4 (VSS), U1.7 (P0W), U2.2 (GND), U3.2 (GND), U5.2 (GND), U6.1 (HVC/A0), U6.4 (VSS), U7.4 (V-); also elsewhere on the board
IO0: U2.3 (!SHDN); also elsewhere on the board
IO1: U3.3 (!SHDN), U5.3 (!SHDN); also elsewhere on the board
IO2: R13.2, U1.6 (P1W); also elsewhere on the board
unnamed: C18.1, L1.2, U7.8 (V+)
S0: U7.1 (OUT), U7.2 (-IN); also elsewhere on the board
S0R: S1.4, U1.8 (P0B), U7.3 (+IN)
S1: U7.6 (-IN), U7.7 (OUT); also elsewhere on the board
S1R: S2.4, U1.5 (P1B), U7.5 (+IN)
S2: R6.2, S1.1; also elsewhere on the board
S3: R5.2, S2.1; also elsewhere on the board
SCL: U1.2 (SCL), U6.2 (SCL); also elsewhere on the board
SDA: U1.3 (SDA), U6.3 (SDA); also elsewhere on the board
VBAT1: C7.1, C11.1, C14.1, U2.1 (VIN), U3.1 (VIN), U5.1 (VIN); also elsewhere on the board
VOUT_0: C8.1, S1.3, U2.5 (VOUT), U6.8 (P0B)
VOUT_1: C12.1, S2.3, U3.5 (VOUT), U6.5 (P1B)
VOUT_2: C15.1, R10.1, S2.2, U5.5 (VOUT); also elsewhere on the board


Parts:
C17: 100n; C0805
R11: 1K; R0805
S3: RHT22

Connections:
+5V: C17.1, R11.1, S3.1 (VDD); also elsewhere on the board
GND: C17.2, S3.4 (GND); also elsewhere on the board
IO3: R11.2, S3.2 (DATA); also elsewhere on the board



Board: 2 copper layers, 66.5 x 56.4 mm, 52 parts (2 on the bottom side), 32 nets.

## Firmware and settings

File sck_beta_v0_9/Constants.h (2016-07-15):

/*

  Constants.h
  Defines ATMEGA32U4 pins and other SENSORS and COMUNICATIONS static parameters.

*/

#define debugEnabled   true
#define decouplerComp   true   //Only for version Goteo 1.0

#if F_CPU == 8000000 
    #define FirmWare  "1.1-0.9.4"
#else
    #define FirmWare  "1.0-0.9.4"
#endif

/* 

WIFI AND SERVER STATICS - WiFly, Http server parameters.

*/
// WiFly Auth Modes
#define OPEN   "0"
#define WEP    "1"
#define WPA    "2"
#define MIXED  "3"
#define WPA2   "4"
#define WEP64  "8"

#define EXT_ANT "1" // External Antenna
#define INT_ANT "0" // Internal Antenna

/* 

WIFLY Firmware Setting

*/

#define networks 0
#if (networks > 0)
static char* mySSID[networks]      = { 
  "SSID1"        , "SSID2"     };
static char* myPassword[networks]  = { 
  "PASS1"      , "PASS2"          };
static char* wifiEncript[networks] = { 
  WPA2         , WPA2                };
static char* antennaExt[networks]  = { 
  INT_ANT      , INT_ANT             };
#endif      

#define TWI_FREQ 400000L //Frecuencia bus I2C

#define WIFLY_LATEST_VERSION 475
#define DEFAULT_WIFLY_FIRMWARE "ftp update wifly3-475.img"
#define DEFAULT_WIFLY_FTP_UPDATE "set ftp address 198.175.253.161"

/* 

ARDUINO ports definitions - GPIOS and ADCs 

*/

#define AWAKE  4      // WIFLY AWAKE
#define PANEL A8      // PANEL LEVEL
#define BAT   A7      // BAT LEVEL 

#define IO0 5         // MICS5525_HEATHER
#define IO1 13        // MICS2710_HEATHER
#define IO2 9         // MICS2710_HIGH_IMPEDANCE
#define IO3 10        // MICS2710_HIGH_IMPEDANCE
#define FACTORY 7     // WIFLY - Factory RESET/AP RN131
#define CONTROL 12    // WIFLY - CONTROL

#define S0 A4         //MICS_5525
#define S1 A5         //MICS_2710
#define S2 A2         //SENS_5525
#define S3 A3         //SENS_2710
#define S4 A0         //MICRO
#define S5 A1         //LDR


/* 

SENSOR READINGS - Defaults

*/

#define DEFAULT_TIME_UPDATE  60     //Time between update and update
#define MIN_TIME_UPDATE      10     //Minimum time between updates (minimum time to read all the sensors)
#define MAX_TIME_UPDATE      3600   //Max time between updates (one hour)
#define DEFAULT_MIN_UPDATES  1      //Minimum number of updates before posting
#define POST_MAX             20     //Max number of postings at a time
#define DEFAULT_MODE_SENSOR  NORMAL     //Type sensors capture (OFFLINE, NOWIFI, NORMAL, ECONOMIC)

/* 

i2c ADDRESSES 

*/
#define RTC_ADDRESS          0x68    // Direction of the RTC
#define E2PROM               0x50    // Direction of the EEPROM

#if F_CPU == 8000000 
  #define MCP1               0x2E    // Direction of the mcp1 Potenciometers that control the MICS
  #define MCP2               0x2F    // Direction of the mcp2 Potenciometers that control the microfone pickup
  #define bh1730             0x29    // Direction of the light sensor
  #define Temperature        0x40    // Direction of the sht21    
  #define ADXL 0x53    //ADXL345 device address
#else
  #define MCP1               0x2F    // Direction of the mcp1 MICS
  #define MCP2               0x2E    // Direction of the mcp2 REGULATORS
#endif

#if F_CPU == 8000000 
  #define R1  12    //Kohm
#else
  #define R1  82    //Kohm
#endif

#define P1  100   //Kohm 


/* 

Internal EEPROM Memory Addresses

*/ 

#define MAX_MEMORY                                  571 //Memory size

// SCK Configuration Parameters 
#define EE_ADDR_TIME_VERSION                        0   //32BYTES 
#define EE_ADDR_TIME_UPDATE                         32  //4BYTES Time between update and update of the sensors in seconds
#define EE_ADDR_SENSOR_MODE                         36  //4BYTES Type sensors capture
#define EE_ADDR_NUMBER_UPDATES                      40  //4BYTES Number of updates before posting
#define EE_ADDR_NUMBER_READ_MEASURE                 44  //4BYTES Number of updates before posting
#define EE_ADDR_NUMBER_WRITE_MEASURE                48  //4BYTES Number of updates before posting
#define EE_ADDR_NUMBER_NETS                         52  //4BYTES Number of networks in the memory 
#define EE_ADDR_APIKEY                              56  //32BYTES Apikey of the device
#define EE_ADDR_MAC                                 100  //32BYTES MAC of the device

// SCK WIFI SETTINGS Parameters
#define DEFAULT_ADDR_SSID                                150  //160 BYTES
#define DEFAULT_ADDR_PASS                                310  //160 BYTES
#define DEFAULT_ADDR_AUTH                                470  //160 BYTES 
#define DEFAULT_ADDR_ANTENNA                             630  //160 BYTES


/* 

External EEPROM Memory Addresses

*/ 

// SCK DATA SPACE (Sensor readings can be stored here to do batch updates)
#define DEFAULT_ADDR_MEASURES                            0


/* 

MICS PARAMETERS - Gas Sensor Addresses and Defaults

*/

#define MICS_5525 0x00
#define MICS_2710 0x01

#define RES 256   // Digital pot. resolution
#define P1  100   //Digital potentiometer resistance 100Kohm

#define  Rc0  10.       //Ohm.  Average current resistance for sensor MICS_5525/MICS_5524

#if F_CPU == 8000000 
  #define  Rc1  39.     //Ohm.  Average current resistance for sensor MICS_2714
#else
  #define  Rc1  10.     //Ohm.  Average current resistance for sensor MICS_2710
#endif

#if F_CPU == 8000000 
  #define  VMIC0 2734.
  #define  VMIC1 2734.
#else
  #define  VMIC0 5000.
  #define  VMIC1 2500.
#endif

#define reference 2560.
#define second 1000
#define minute 60000

/* 

BATTERY PARAMETERS - Battery sensing calibration parameters

*/

#if F_CPU == 8000000 
  #define  VAL_MAX_BATTERY                             4200
  #define  VAL_MIN_BATTERY                             3000
#else
  #define  VAL_MAX_BATTERY                             4050
  #define  VAL_MIN_BATTERY                             3000
#endif


#define DHTLIB_INVALID_VALUE    -999

#define OFFLINE   0  //No connect to server
#define NOWIFI    1  //No connect arduino to wifi module
#define NORMAL    2  //Nomal mode o real time
#define ECONOMIC  3  //Economic mode, sensor gas active one time for hour

#define  SENSORS 9  //Numbers of sensors in the board

#define buffer_length        32
static char buffer[buffer_length];

// Basic Server Posts to the SmartCitizen Platform - EndPoint: http://data.smartcitizen.me/add 
static char* WEB[8]={
                  "data.smartcitizen.me",
                  "PUT /add HTTP/1.1\n", 
                  "Host: data.smartcitizen.me \n", 
                  "User-Agent: SmartCitizen \n", 
                  "X-SmartCitizenMacADDR: ", 
                  "X-SmartCitizenApiKey: ", 
                  "X-SmartCitizenVersion: ",  
                  "X-SmartCitizenData: "};
  
// Time server request -  EndPoint: http://data.smartcitizen.me/datetime                 
static char* WEBTIME[3]={                  
                  /*Servidor de tiempo*/
                  "GET /datetime HTTP/1.1\n",
                  "Host: data.smartcitizen.me \n",
                  "User-Agent: SmartCitizen \n\n"  
                  };

// Data JSON structure                  
static char* SERVER[11]={
                  "{\"temp\":\"",
                  "\",\"hum\":\"", 
                  "\",\"light\":\"",
                  "\",\"bat\":\"",
                  "\",\"panel\":\"",
                  "\",\"co\":\"", 
                  "\",\"no2\":\"", 
                  "\",\"noise\":\"", 
                  "\",\"nets\":\"", 
                  "\",\"timestamp\":\"", 
                  "\"}"
                  };
                  
static char* SENSOR[10]={
                  "Temperature: ",
                  "Humidity: ",
                  "Light: ",
                  "Battery: ",
                  "Solar Panel: ",
                  "Carbon Monxide: ",
                  "Nitrogen Dioxide: ",
                  "Noise: ",
                  "Wifi Spots: ",
                  "UTC: " 
                };

static char* UNITS[9]={
                  #if F_CPU == 8000000 
                    " C RAW",
                    " % RAW",
                  #else
                    " C",
                    " %",
                  #endif
                  #if F_CPU == 8000000 
                    " lx",
                  #else
                    " %",
                  #endif
                    " %",
                    " mV",
                    " kOhm",
                    " kOhm",
                    " mV",
                    "",
                  };  

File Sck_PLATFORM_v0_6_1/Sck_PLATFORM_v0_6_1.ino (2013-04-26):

#include <Wire.h>

#include "SmartCitizenAmbient.h"
#include "TimerOne.h"

#define transmit 60 //Tiempo entre transmision y transmision en segundos, minimo 60 segundos
#define time_int 500 //Tiempo de atencion a la interrupcion en microsegundos
unsigned long timetransmit;

#define USBEnabled      true 
#define wiflyEnabled    true  
#define SDEnabled       false
#define sensorEnabled   true
#define debuggEnabled   true

SmartCitizen sck;

boolean wait        = false;
boolean sleep       = true; 
boolean ap_mode     = false;
boolean iphone_mode = false;
byte server_mode    = 0;

boolean eeprom_write_ssid    = false;
boolean eeprom_write_pass    = false;
boolean eeprom_write_ok      = false;
boolean eeprom_read_ssid     = false;
boolean eeprom_read_pass     = false;
boolean eeprom_read_ok       = false;
unsigned int address_eeprom  = 0;
uint16_t  nets                = 0;

byte check_ssid_read         = 0;
byte check_ssid_write        = 0;
byte check_pass_write        = 0;
byte check_pass_read         = 0;
byte check_auth_write        = 0;
byte check_auth_read         = 0;
byte check_clear             = 0;

byte check_data_read          = 0;
byte check_terminal_mode      = 0;
byte check_terminal_exit      = 0;
byte check_telnet_open        = 0;
byte check_telnet_close       = 0;

void timerIsr()
{
  sei();
  if (Serial.available())
  {
    byte inByte = Serial.read();  
    if (sck.check_text(inByte, "exit\r", &check_terminal_exit)) wait = false;
    if (sck.check_text(inByte, "$$$", &check_terminal_mode))
    {
      digitalWrite(AWAKE, HIGH); 
      delayMicroseconds(100);
      digitalWrite(AWAKE, LOW);
      wait = true;
    }
    Serial1.write(inByte);
  }

  if (Serial1.available()) 
  {
    byte inByte = Serial1.read();
    if (sck.check_text(inByte, "*OPEN*", &check_telnet_open))  { 
      wait = true; 
      server_mode = 0;
    }
    if (sck.check_text(inByte, "*CLOS*", &check_telnet_close)) { 
      wait = false; 
      server_mode = 1;
    }
    if (sck.check_text(inByte, "#data\r", &check_data_read))  
    { 
      uint16_t temp = sck.readintEEPROM(EE_ADDR_POST_MEASURES);
      if (temp > 0) { 
        iphone_mode = true; 
        wait = true; 
        server_mode = 0;
      }
      Serial1.print("updates: ");
      Serial1.println(temp);
    }
    Serial.write(inByte); 
  }
}

#if SDEnabled
#include <SD.h>
File myFile;

long SENSORvalue[8];

#endif

void setup() {

  Serial.begin(115200);
  Serial1.begin(9600);
  sck.begin();

  pinMode(IO0, OUTPUT); //VH_MICS5525
  pinMode(IO1, OUTPUT); //VH_MICS2710
  pinMode(IO2, OUTPUT); //MICS2710_ALTAIMPEDANCIA
  pinMode(AWAKE, OUTPUT);
  pinMode(MOSI, OUTPUT);
  pinMode(SCK, OUTPUT);
  digitalWrite(IO0, LOW); //VH_MICS5525
  digitalWrite(IO1, LOW); //VH_MICS2710
  digitalWrite(IO2, LOW); //RADJ_MICS2710
  digitalWrite(AWAKE, LOW); 

#if SDEnabled
  sck.sleep();
#if debuggEnabled
  Serial.print(F("Initializing SD card..."));
#endif 
  if (!SD.begin(11)) {
#if debuggEnabled
    Serial.println(F("initialization failed!"));
#endif 
    return;
  }
#if debuggEnabled
  Serial.println(F("initialization done."));   
#endif 
  if (!SD.exists("post.txt")) {
#if debuggEnabled
    Serial.println(F("Creating post.txt..."));
#endif 
    myFile = SD.open("post.txt", FILE_WRITE);
    myFile.close();
  }
#endif   

  /*init WiFly*/
#if wiflyEnabled
  digitalWrite(AWAKE, HIGH); 
  server_mode = 1;
  if (transmit < 60) sleep = false;
  else sleep = true;

  config();  

  if (!sck.connect())
  {
    sleep = false;  
    ap_mode = true;
    sck.APmode(sck.id());
#if debuggEnabled
    Serial.println(F("AP initialized!"));
#endif 
  }
  else
  {
#if debuggEnabled
    Serial.println(F("wifly connected!"));
#endif
    byte retry = 0;
    while (!sck.RTCadjust(sck.WIFItime())&&(retry<5)) {
      retry = retry + 1;
    }
  }  

  if(sleep)
  {
    sck.sleep();
#if debuggEnabled
    Serial.println(F("Duerme")); 
#endif
    digitalWrite(AWAKE, LOW); 
  }
#else  
  server_mode = 2; 
#endif  

  Timer1.initialize(time_int); // set a timer of length 1000000 microseconds (or 1 sec - or 1Hz)
  Timer1.attachInterrupt( timerIsr ); // attach the service routine here   
  timetransmit = millis();
}

void loop() {    
#if sensorEnabled  
  if (!ap_mode)
  {
    if (iphone_mode) // Telnet  (#data + *OPEN* detectado )
    {
      Timer1.stop();
      sleep = false;
      digitalWrite(AWAKE, HIGH);
      sck.json_updtate();
      iphone_mode = false;
      Timer1.initialize(time_int); // set a timer of length 1000000 microseconds (or 1 sec - or 1Hz)
    }
    if ((millis()-timetransmit) >= (unsigned long)transmit*1000)
    { 
      timetransmit = millis();
      sck.updateSensors(server_mode);
      if (!wait) // command mode false
      {
        Timer1.stop();
#if wiflyEnabled
        if (server_mode) txWiFly();
#endif
#if SDEnabled
        txSD();
#endif
#if USBEnabled
        txDebug();
#endif
        Timer1.initialize(time_int); // set a timer of length 1000000 microseconds (or 1 sec - or 1Hz)
      }
    }
  }
#endif
}

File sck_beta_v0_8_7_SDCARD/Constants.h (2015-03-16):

#define debuggSCK     false
#define decouplerComp true
#define DataRaw       false

#define AWAKE  4 //Despertar WIFI
#define PANEL A8 //Entrada panel
#define BAT   A7 //Entrada bateria

#define IO0 5  //MICS5525_HEATHER
#define IO1 13 //MICS2710_HEATHER
#define IO2 9  //MICS2710_ALTAIMPEDANCIA
#define IO3 10  //MICS2710_ALTAIMPEDANCIA
#define FACTORY 7  //factory RESET/AP RN131
#define CONTROL 12  //Control Mode

#define S0 A4 //MICS_5525
#define S1 A5 //MICS_2710
#define S2 A2 //SENS_5525
#define S3 A3 //SENS_2710
#define S4 A0 //MICRO
#define S5 A1 //LDR

#define DEFAULT_TIME_UPDATE  "30"     //Tiempo entre actualizacion y actualizacion
#define DEFAULT_MIN_UPDATES  "1"      //Minimo numero de actualizaciones antes de postear

#define POST_MAX             20       //Maximo numero de posteos a la vez

//Direcciones I2C
#define RTC_ADDRESS          0x68    // Direcion de la RTC
#define E2PROM               0x50    // Direcion de la EEPROM

#if F_CPU == 8000000 
  #define MCP1               0x2E    // Direcion del mcp1 Potenciometros que controlan los MICS
  #define MCP2               0x2F    // Direcion del mcp2 Potenciometros que controlan la ganancia del microfono
  #define MCP3               0x2D    // Direcion del mcp3 Ajuste carga bateria
  #define bh1730             0x29    // Direcion del sensor de luz
  #define Temperature        0x40    // Direcion del sht21    
  #define ADXL 0x53    //ADXL345 device address
#else
  #define MCP1               0x2F    // Direcion del mcp1 MICS
  #define MCP2               0x2E    // Direcion del mcp2 REGULADORES
#endif

//Espacio reservado para los parametros de configuracion del SCK  
#define EE_ADDR_TIME_VERSION                        0   //32BYTES 
#define EE_ADDR_TIME_UPDATE                         32  //16BYTES Tiempo entre actualizacion y actualizacion de los sensores en segundos
#define EE_ADDR_NUMBER_UPDATES                      48  //4BYTES  Numero de actualizaciones antes de postear


#define MICS_5525 0x00
#define MICS_2710 0x01

#define  Rc0  10. //Ohm  Resistencia medica de corriente en el sensor MICS_5525/MICS_5524

#if F_CPU == 8000000 
  #define  Rc1  39. //Ohm Resistencia medica de corriente en el sensor MICS_2714
#else
  #define  Rc1  10. //Ohm Resistencia medica de corriente en el sensor MICS_2710
#endif

#if F_CPU == 8000000 
  float    Vcc = 3300.; //mV 
  #define  VMIC0 2734.
  #define  VMIC1 2734.
#else
  float    Vcc = 5000.; //mV 
  #define  VMIC0 5000.
  #define  VMIC1 2500.
#endif

#define reference 2560.

#if F_CPU == 8000000 
  #define  VAL_MAX_BATTERY                             4200
  #define  VAL_MIN_BATTERY                             3000
#else
  #define  VAL_MAX_BATTERY                             4050
  #define  VAL_MIN_BATTERY                             3000
#endif


#define DHTLIB_INVALID_VALUE    -999

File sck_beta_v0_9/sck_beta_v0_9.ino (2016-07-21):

/*

  Smart Citizen Kit
  Ambient Board Beta Firmware v. 0.9.4

  http://smartcitizen.me/


  Compatible:

    Smart Citizen Kit v.1.0 (Goteo)       (ATMEGA32U4 @ 16Mhz - Arduino Leonardo profile)
    Smart Citizen Kit v.1.1 (Kickstarter) (ATMEGA32U4 @ 8Mhz  - Lylipad Arduino USB)

  Structure:
    
    sck_beta_v0_9.ino - Core Runtime.

    SCKAmbient.h    - Supports the sensor reading and calibration functions.
    SCKBase.h       - Supports the data management functions (WiFi,  RTClock and EEPROM storage)
    SCKServer.h     - Supports data publishing to the SmartCitizen Platform over WiFi.

    Constants.h             - Defines pins configuration and other static parameters.
    AccumulatorFilter.h     - Used for battery temperature decoupling in  Smart Citizen Kit v.1.0 
    TemperatureDecoupler.h  - Used for battery temperature decoupling in  Smart Citizen Kit v.1.0 

  Check REAMDE.md for more information.
    
*/

#include <Wire.h>
#include <EEPROM.h>
#include "SCKAmbient.h"

SCKAmbient ambient;
  
void setup() {
  ambient.begin();
  ambient.ini();
  ambient.execute(true);
}

void loop() {  
  ambient.execute(false);
}

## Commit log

2013-02-11 Added sketch to control wifly module using Arduino terminal. Recommended update firmware after connecting to wifly network. Command: "ftp upload" + enter
2013-02-12 Added sketch to control wifly module using Arduino terminal. Recommended update firmware after connecting to wifly network.
2013-04-26 Solved problem with smart citizen kit usb configuration using Smart Citizen platform.
    [Sck_PLATFORM_v0_6_1.ino, SmartCitizenAmbient.cpp]
2013-06-01 solved problem when wifi is disconnected for a long time!
    [ServerUpdate.ino, SmartCitizenAmbient.cpp, SmartCitizenAmbient.h]
2013-07-24 Eagles files of Goteo.org campaign http://www.goteo.org/project/smart-citizen-sensores-ciudadanos
    Smart Citizen Kit BETA version
    - Base Board v1.0
    - Ambient Sensor Board v1.0
    [SCK_Ambient_v1.0.brd, SCK_Ambient_v1.0.sch, SCK_Base_v1.0.brd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]
2013-07-24 Base Board v1.01 Some improvements:
    - Wifly 3V3 RIN connected to GND
    - Adding new diode for the battery of RTC
    [SCK_Ambient_v1.0.brd, SCK_Ambient_v1.0.sch, SCK_Base_v1.01.brd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]
2013-08-11 Some problems with eagle original files. Uploaded sources in zip format.
    [SCK_Ambient_v1.0.brd, SCK_Ambient_v1.0.sch, SCK_Base_v1.0.brd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]
2013-10-01 Nueva versión
    Se a eliminado gran parte de la libreria SmartCitizen y simplificado
    alguna funciones.
    Añadida compatibilidad a la version 1.1 del SCK Board y Ambient
2013-10-01 Fallo corregido provisionalmente, tiene un desbordamiento de memoria y solo acepta preconfigurar dos redes de memoria.
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2013-10-08 Adquirida compensacion de temperatura by armadillu
2013-10-08 Adquirida mencion al creador de la libreia I2C utilizada
2013-10-12 Correccion en la gestion de la lectura de los sensores de gas
2013-10-19 Correcciones en los sensores de gas
2013-10-19 Correccion de valores negativos de temperatura que provocaba un error al postear
    [SCKBase.ino]
2013-10-20 Adquirida ecuación de conversión a ppm de los sensores de gas
    [Grafica_MICS.xls]
2013-10-27 Proteccion para que la lectura de los MICS no se quede bloqueada cuando es un valor bajo.
2013-10-27 Cambios introducidos por aposada
    [Grafica_MICS_v1.1.xls]
2013-10-27 Correcciones en la SD
2013-10-28 Corregido fallo en el primer post del sensor de luz
2013-10-28 Modificacion para que el sck v1.1 transmita la temperatura en RAW
2013-10-28 Añadido ajuste de reloj de la RTC cada vez que conecta al servidor.
2013-11-04 Actualizada la RTC al chip DS1339
2013-12-09 Limpieza de codigo y se puede seleccionar entre modo RAW y "normal"
2013-12-09 Corregido fallo en la lectura de dB
2013-12-09 Nueva version del firmware
    [Grafica_MICS.xls, Grafica_MICS_v1.1.xls]
2013-12-09 Revert "Nueva version del firmware"
    This reverts commit 14413ed2e1d3c47728bc4939659fe5b9d16b2a45.
    [Grafica_MICS.xls, Grafica_MICS_v1.1.xls]
2013-12-09 Revert "Revert "Nueva version del firmware""
    This reverts commit 48708747a4e2fb564135b2baacb12a41b3a75624.
    [Grafica_MICS.xls, Grafica_MICS_v1.1.xls]
2013-12-09 Revert "Revert "Revert "Nueva version del firmware"""
    This reverts commit 76695489e06d827ac74d6207b5496909c3cbbf43.
    [Grafica_MICS.xls, Grafica_MICS_v1.1.xls]
2013-12-09 Adquirida nueva version del firmware utilizando las librerias I2C Standard
2013-12-09 Correcciones en la RTC
2013-12-11 Activado modo "RAW" y adquirida lista de comandos.
2013-12-12 Actualizado nivel maximo de bateria en sck 1.0
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2013-12-14 Adquirido nuevo comando para setear el numero de actualizaciones a la vez
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2014-01-09 Deshabilitado el modo AP automatico cuando no detecta redes disponibles.
    Ahora solo entra en modo AP cuando se arranca la placa por primera vez.
2014-01-09 Habilitado modo AD HOC por hardware en el SCK v1.1
2014-01-09 Adquirido comando #data para visualizar los datos de la EEPROM
2014-01-09 Adquirido nuevo comando en la lista de comandos
2014-01-14 manual cleaning
    [Grafica_MICS.xls, Grafica_MICS_v1.1.xls]
2014-01-16 Correccion en la lectura de la EEPROM que puede producir cuelgue del kit
2014-01-16 Importante!! Corrección en la constante VCC, que produce que los valores leeidos en todos los SCK v1.1 sean erroneos!!
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2014-02-03 prevent WiFly bridge on CMD mode
    Prevents the WiFly module bridge to send serial data when on CMD mode
    [SerialRequests.ino]
2014-02-03 serial bridge WiFly to USB limited CMD Mode
    WiFly Serial Bridge limited to WiFly commands mode to prevent undesired
    debug info when in SCK command mode
    [SerialRequests.ino]
2014-03-18 New utilities and compensation of analog reference voltage
    Utilities:
    Wifly_Update.ino
    Wifly_Rescue.ino
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2014-03-21 debug mode changes
    debug changes to improve web conf. issues
    [SCKBase.ino]
2014-03-22 Fixed bug in terminal mode
    [SerialRequests.ino, ServerUpdate.ino]
2014-04-18 Increased EEPROM memory capacity of 100 to 570 post
2014-04-22 DataRaw FirmwareVersion preprocessor bug
    [SCKAmbient.ino]
2014-05-03 Correction in economic mode
    [SCKAmbient.cpp]
2014-08-09 - Added GNU GPL license in all files. - Implemented 'set apikey' command. - Added 'base_.' prefix in in heat(.) function.
2014-08-10 Created functions to prevent code redundancy
    [SCKAmbient.cpp]
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2014-08-11 Created functions readByte and writeByte to prevent code redundancy
    [SCKBase.cpp]
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2014-10-07 Fixed bug in the introduction of very long SSID and PASS.
    [SCKAmbient.cpp]
2014-10-12 fixed bug in autoupdate
    [SCKBase.cpp]
2014-10-12 Revert "fixed bug in autoupdate"
    This reverts commit 623a83500125bb66108c16e2cb8840cebe86df68.
    [SCKBase.cpp]
2014-10-12 Revert "Revert "fixed bug in autoupdate""
    This reverts commit a4de0910d0964d00a6f5348200d6ab2b041a2435.
    [SCKBase.cpp]
2014-11-02 Bug in addData, due to bad merge
    [SCKAmbient.cpp]
2014-11-19 Missing base_. when begun mode is on
    Small change adding base._average in line 329
    [SCKAmbient.cpp]
2014-12-01 Updating the EAGLE doc
    [SCK_Ambient_v1.0.brd, SCK_Ambient_v1.0.sch, SCK_Base_v1.0.brd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]
2015-06-07 Custom backend example
    [data.csv]
2015-06-23 Fix HTTP message formatting to be RFC2616 (section 5.1) compliant, and hence so they will pass through a transparent Squid proxy
    [Constants.h]
2015-07-16 Fix overflow on serial, print txDebug
    [SCKAmbient.cpp]
2015-07-31 Revert 535b851..45a6503
    This rolls back to commit 535b851528311b3f5b8fb4cbbe1c756d15124a54.
    [Constants.h, SCKAmbient.cpp, SCKBase.cpp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]
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2016-03-15 Revert "Disable LED's command"
    This reverts commit dd180889e35dd74b51b57e7c625ea07c6de8cff8.
2016-04-10 Added eeprom memory sanity check on boot.
    -Removed __TIME__ as the method for detecting first boot, since it's behavior is not the same in all systems.
    -Added function eepromCheck() that checks eeprom variable sanity and if necessary executes a clearmemory().
    -eepromCheck() also checks for hardcoded nets and overwrite them if necessary.
    -Updated "clear nets" command to only clear non harcoded networks (allowing use of the remaining slots for nets added by configurator).
2016-04-10 New command "get all"
    -Added new command "get all" for retrieving all config info from the kit in a single line, it's fast :).
    -Changed printNetWorks() function so it can output data without new line at the end.
2016-04-10 Fix wrong timestamp after connection error.
    When sending multiple posts after a connection error all the timestamps but the last one where the same.
    It wasn't getting RTC time before saving the post to memory.
    [SCKServer.cpp]
2016-04-14 Don't send data if RTC hasn't been updated since boot
    -If RTC is not working don't capture and don't send data, make error visible to user (blue leds keep blinking permanently).
    -Added function RTCupdate() grouping commands.
    -version change to 0.9.3-A
    -Minor changes
    [Constants.h, SCKAmbient.cpp, SCKServer.cpp]
2016-04-25 Minor bug fix
    - Don't print debug message if we are in command mode
    [SCKServer.cpp]
2016-05-05 New command "post data"
    Retrieve sensor readings and post them to server if network connection is available.
2016-06-02 Fix for unnecessary clear memory
    The function MAC() now returns -1 when wifly don't give us a valid mac address.
    Keep asking wifly for mac address until we get a valid response, avoiding unnecessary clearMemory().
    [SCKBase.cpp]
2016-06-06 Fix error that prevents certain commands to work
    Added second parameter when calling printNetworks from _get wlan_ commands
    [SCKAmbient.cpp]
2016-06-09 New battery percent calculation
    Based on a lookup table now battery percent reporting is more accurate.
2016-06-16 Improved Wifi management
    * Removed automatic entering in APmode if no network is configured yet.
    * Report error in wifi connection including ssid and pass used.
    * If no connection has been made since boot don't enter sleep mode, keep trying and make error visible with blue leds.
    * Try to make a post immediately after boot.
    * Now a reboot is not needed after changed networks via the configurator if no connection has been made since boot.
    [SCKAmbient.cpp, sck_beta_v0_9.ino]
2016-06-17 Minor added feedback on connection error
    [SCKAmbient.cpp]
2016-06-17 Fix issue #38 "Update times are not regular"
    [SCKServer.cpp]
2016-06-21 Support again coin cell battery RTC in case of temporary network error.
    [SCKAmbient.cpp, SCKBase.cpp, SCKServer.cpp]
2016-07-22 SCK 1.1 enclosure first commit
    [SCK-1.1_case_acrylic.dxf, SCK-1.1_case_clip.stl, SCK-1.1_simple_base.stl]
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2016-07-25 Added old case and reorganize.
    [SCK-1.0_acrylic.dxf, SCK-1.0_case.stl, SCK-1.1_acrylic.dxf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]
2016-07-25 more reorganization.
    [SCK-1.1_case_acrylic.dxf, SCK-1.1_case_clip.stl, SCK-1.1_simple_base.stl]
2016-10-25 Create Smart Citizen SCK Mock-Up
    Smart Citizen SCK Mock-Up that can be 3D printed for testing and fitting so the real hardware won't need to be used.
2016-10-25 Dummy Base Plate
    Dummy Base Plate .STL File for 3D printing.
    [dummybaseplate2.stl]
2019-06-21 Fix broken image to 1.0 board

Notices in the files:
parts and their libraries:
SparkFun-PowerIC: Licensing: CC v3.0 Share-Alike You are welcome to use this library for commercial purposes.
